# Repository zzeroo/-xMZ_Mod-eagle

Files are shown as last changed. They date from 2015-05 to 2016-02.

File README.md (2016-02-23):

# xMZ-Mod-Touch Eagle Files

Eagle files for the 'xMZ-Mod-Touch' project.

# Material Listen (BOM)

Die Material Listen werden aus den Eagle Zeichnungen gewonnen. Hierzu werden in
Eagle zunächst über den "design link" alle Bauteile in der Farnell Datenbank
gesucht.
Anschließend wird diese Liste gespeichert.

* Datei: "Deckelplatine $VERSION-order.txt"

Danach wird das bom.ulp in Eagle ausgeführt. Folgende Einstellungen sind zu
wählen:

	Listen-Typ: Werte (Häckchen unter "Attribute auflisten" setzen)
	Ausgabeformat: CSV

Diese Datei wird ebenfalls gespeichert.

* Datei: "Deckelplatine $VERSION BOM.csv"

### Farnell BOM Import

Farnell bietet die Möglichkeit über eine Web GUI die BOM Daten in eine
Bestellung umzuwandeln.

Format der CSV Datei für den Import:
- 3 Spalten
"Anzahl	Ordercode	Beschreibung"
- Dateiformat .xls

#Produktionsdaten
## Boardlayout Dateien

Einige der wichtigsten Ebenen (Drill, Solder, Paste) wurden einzeln mit der
Document (Layer 48) Ebene als PDF gedruckt

gs -dBATCH -dNOPAUSE -q -sDEVICE=pdfwrite -sOutputFile=Bodenplatine.pdf \
"Bodenplatine Dimensions.pdf" \
"Bodenplatine Placement TOP.pdf" \
"Bodenplatine PCB: TOP Layer.pdf" \
"Bodenplatine PCB: BOTTOM Layer.pdf" \
"Bodenplatine TOP Paste.pdf" \
"Bodenplatine TOP Solder Mask.pdf" \
"Bodenplatine Drill Drawing.pdf"

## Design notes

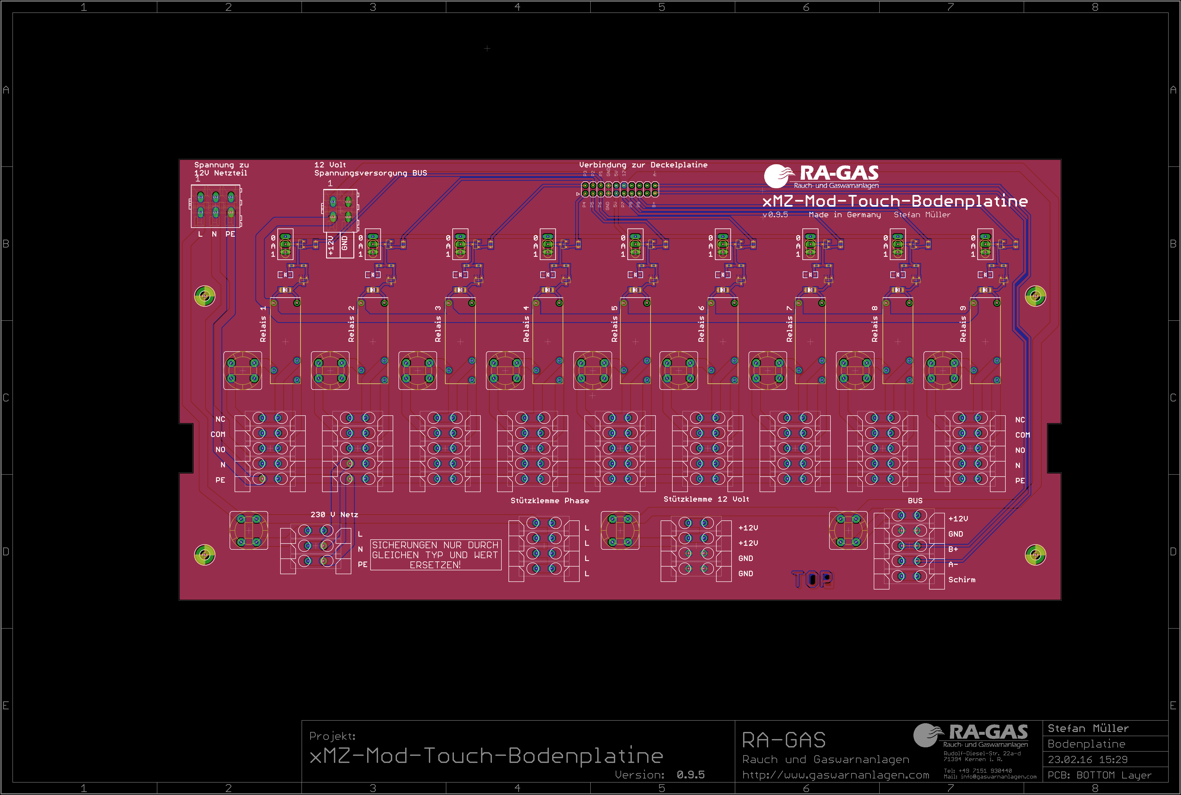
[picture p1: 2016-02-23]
Bodenplatine.png

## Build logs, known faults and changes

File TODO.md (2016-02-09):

# Deckelplatine

* Relais shift registers mit pull down/ pull up ausschalten bis der Banana Pro sie manuell aktiviert.

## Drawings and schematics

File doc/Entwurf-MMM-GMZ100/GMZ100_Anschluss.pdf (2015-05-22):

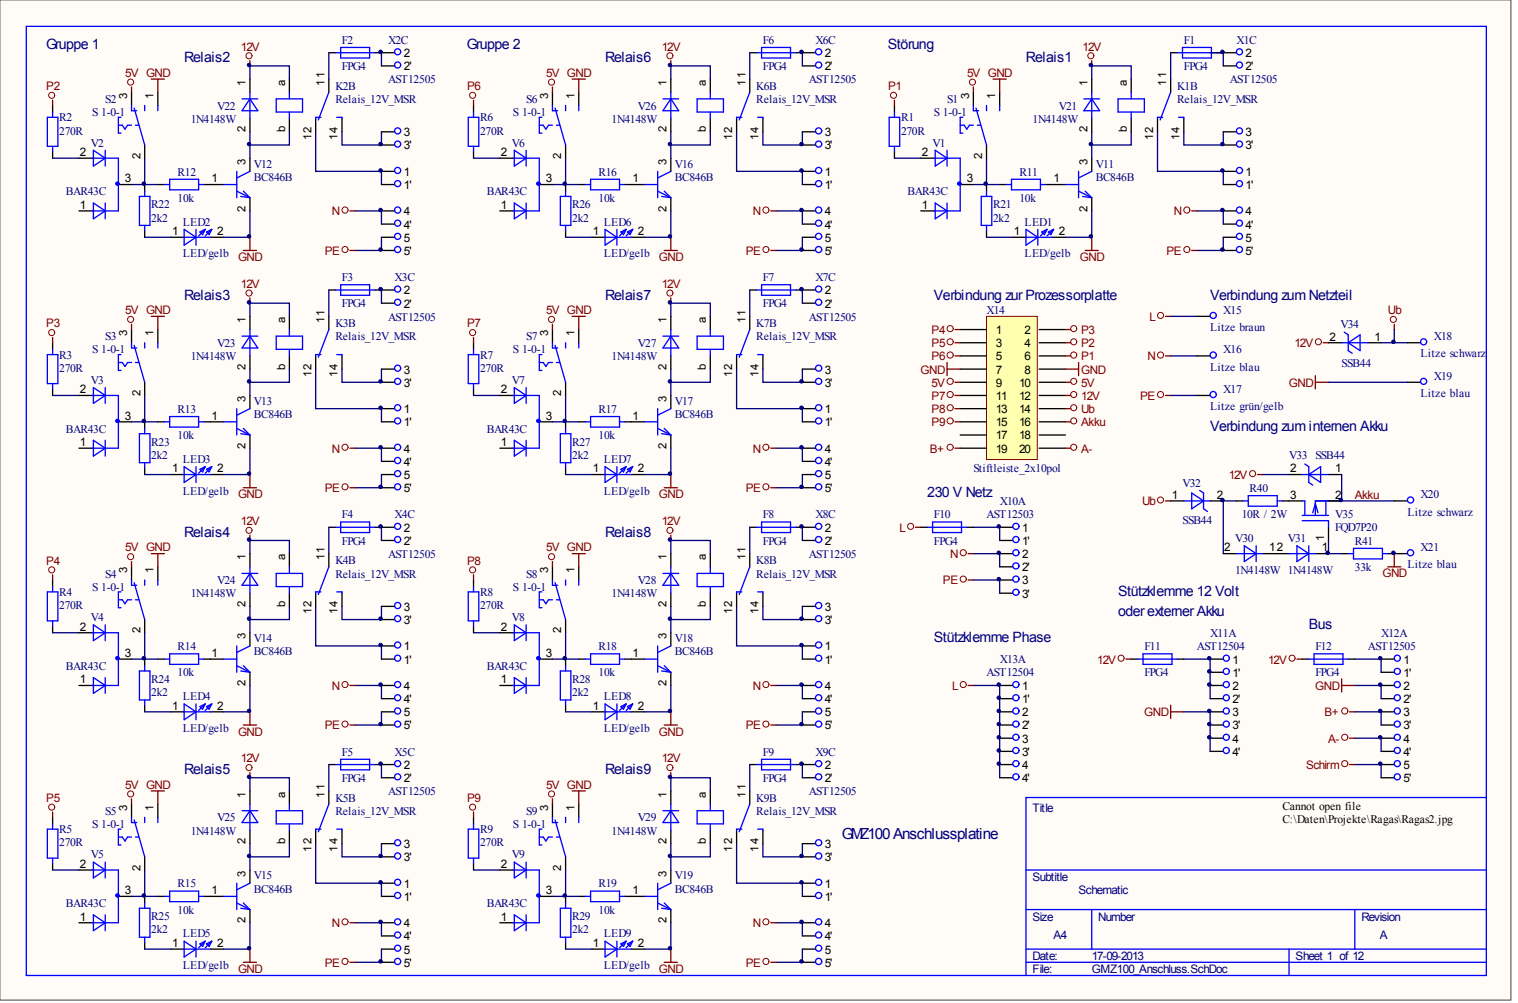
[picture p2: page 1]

Litze grün/gelb
Verbindung zum internen Akku

Cannot open file
C:\Daten\Projekte\Ragas\Ragas2.jpg

Size A4 | Number | Revision A

Date: 17-09-2013 | Sheet 1 of 12
File: GMZ100_Anschluss.SchDoc

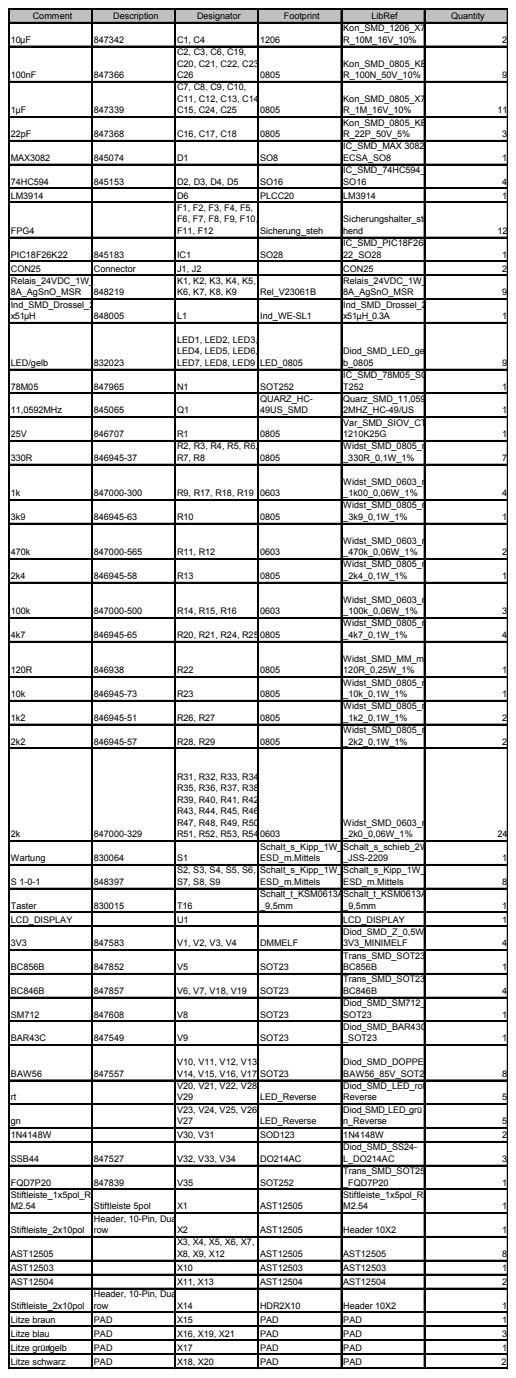
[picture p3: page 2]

Comment | Description | Designator | Footprint | LibRef | Quantity
10µF | 847342 | C1, C4 | 1206 | Kon_SMD_1206_X7 R_10M_16V_10% | 2

100nF | 847366 | C2, C3, C6, C19, C20, C21, C22, C23, C26 | 0805 | Kon_SMD_0805_KE R_100N_50V_10% | 9

1µF | 847339 | C7, C8, C9, C10, C11, C12, C13, C14, C15, C24, C25 | 0805 | Kon_SMD_0805_X7 R_1M_16V_10% | 11

22pF | 847368 | C16, C17, C18 | 0805 | Kon_SMD_0805_KE R_22P_50V_5% | 3

MAX3082 | 845074 | D1 | SO8 | IC_SMD_MAX 3082 ECSA_SO8 | 1

74HC594 | 845153 | D2, D3, D4, D5 | SO16 | IC_SMD_74HC594_ SO16 | 4

LM3914 | | D6 | PLCC20 | LM3914 | 1
FPG4 | | F1, F2, F3, F4, F5, F6, F7, F8, F9, F10, F11, F12 | Sicherung_steh | Sicherungshalter_ste hend | 12

PIC18F26K22 | 845183 | IC1 | SO28 | IC_SMD_PIC18F26k 22_SO28 | 1

CON25 | Connector | J1, J2 | | CON25 | 2
Relais_24VDC_1W_ 8A_AgSnO_MSR | 848219 | K1, K2, K3, K4, K5, K6, K7, K8, K9 | Rel_V23061B | Relais_24VDC_1W_ 8A_AgSnO_MSR | 9

Ind_SMD_Drossel_2 x51µH | 848005 | L1 | Ind_WE-SL1 | Ind_SMD_Drossel_2 x51µH_0.3A | 1

LED/gelb | 832023 | LED1, LED2, LED3, LED4, LED5, LED6, LED7, LED8, LED9 | LED_0805 | Diod_SMD_LED_gel b_0805 | 9

78M05 | 847965 | N1 | SOT252 | IC_SMD_78M05_SO T252 | 1

11,0592MHz | 845065 | Q1 | QUARZ_HC-49US_SMD | Quarz_SMD_11,059 2MHZ_HC-49/US | 1

25V | 846707 | R1 | 0805 | Var_SMD_SIOV_CT 1210K25G | 1

330R | 846945-37 | R2, R3, R4, R5, R6, R7, R8 | 0805 | Widst_SMD_0805_m _330R_0,1W_1% | 7

1k | 847000-300 | R9, R17, R18, R19 | 0603 | Widst_SMD_0603_m _1k00_0,06W_1% | 4

3k9 | 846945-63 | R10 | 0805 | Widst_SMD_0805_m _3k9_0,1W_1% | 1

470k | 847000-565 | R11, R12 | 0603 | Widst_SMD_0603_m _470k_0,06W_1% | 2

2k4 | 846945-58 | R13 | 0805 | Widst_SMD_0805_m _2k4_0,1W_1% | 1

100k | 847000-500 | R14, R15, R16 | 0603 | Widst_SMD_0603_m _100k_0,06W_1% | 3

4k7 | 846945-65 | R20, R21, R24, R25 0805 | | Widst_SMD_0805_m _4k7_0,1W_1% | 4

120R | 846938 | R22 | 0805 | Widst_SMD_MM_m 120R_0,25W_1% | 1

10k | 846945-73 | R23 | 0805 | Widst_SMD_0805_m _10k_0,1W_1% | 1

1k2 | 846945-51 | R26, R27 | 0805 | Widst_SMD_0805_m _1k2_0,1W_1% | 2

2k2 | 846945-57 | R28, R29 | 0805 | Widst_SMD_0805_m _2k2_0,1W_1% | 2

2k | 847000-329 | R31, R32, R33, R34, R35, R36, R37, R38, R39, R40, R41, R42, R43, R44, R45, R46, R47, R48, R49, R50, R51, R52, R53, R54 0603 | | Widst_SMD_0603_m _2k0_0,06W_1% | 24

Wartung | 830064 | S1 | Schalt_s_Kipp_1W_ ESD_m.Mittels | Schalt_s_schieb_2W _JSS-2209 | 1

S 1-0-1 | 848397 | S2, S3, S4, S5, S6, S7, S8, S9 | Schalt_s_Kipp_1W_ ESD_m.Mittels | Schalt_s_Kipp_1W_ ESD_m.Mittels | 8

Taster | 830015 | T16 | Schalt_t_KSM0613A _9,5mm | Schalt_t_KSM0613A _9,5mm | 1

LCD_DISPLAY | | U1 | | LCD_DISPLAY | 1
3V3 | 847583 | V1, V2, V3, V4 | DMMELF | Diod_SMD_Z_0,5W_ 3V3_MINIMELF | 4

BC856B | 847852 | V5 | SOT23 | Trans_SMD_SOT23_ BC856B | 1

BC846B | 847857 | V6, V7, V18, V19 | SOT23 | Trans_SMD_SOT23_ BC846B | 4

SM712 | 847608 | V8 | SOT23 | Diod_SMD_SM712_ SOT23 | 1

BAR43C | 847549 | V9 | SOT23 | Diod_SMD_BAR43C _SOT23 | 1

BAW56 | 847557 | V10, V11, V12, V13, V14, V15, V16, V17 | SOT23 | Diod_SMD_DOPPEL BAW56_85V_SOT23 | 8

rt | | V20, V21, V22, V28, V29 | LED_Reverse | Diod_SMD_LED_rot_ Reverse | 5

gn | | V23, V24, V25, V26, V27 | LED_Reverse | Diod_SMD_LED_grü n_Reverse | 5

1N4148W | | V30, V31 | SOD123 | 1N4148W | 2
SSB44 | 847527 | V32, V33, V34 | DO214AC | Diod_SMD_SS24-L_DO214AC | 3

FQD7P20 | 847839 | V35 | SOT252 | Trans_SMD_SOT252 _FQD7P20 | 1

Stiftleiste_1x5pol_R M2.54 | Stiftleiste 5pol | X1 | AST12505 | Stiftleiste_1x5pol_R M2.54 | 1

Stiftleiste_2x10pol | Header, 10-Pin, Dual row | X2 | AST12505 | Header 10X2 | 1

AST12505 | | X3, X4, X5, X6, X7, X8, X9, X12 | AST12505 | AST12505 | 8

AST12503 | | X10 | AST12503 | AST12503 | 1
AST12504 | | X11, X13 | AST12504 | AST12504 | 2
Stiftleiste_2x10pol | Header, 10-Pin, Dual row | X14 | HDR2X10 | Header 10X2 | 1

Litze braun | PAD | X15 | PAD | PAD | 1
Litze blau | PAD | X16, X19, X21 | PAD | PAD | 3
Litze grün/gelb | PAD | X17 | PAD | PAD | 1
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

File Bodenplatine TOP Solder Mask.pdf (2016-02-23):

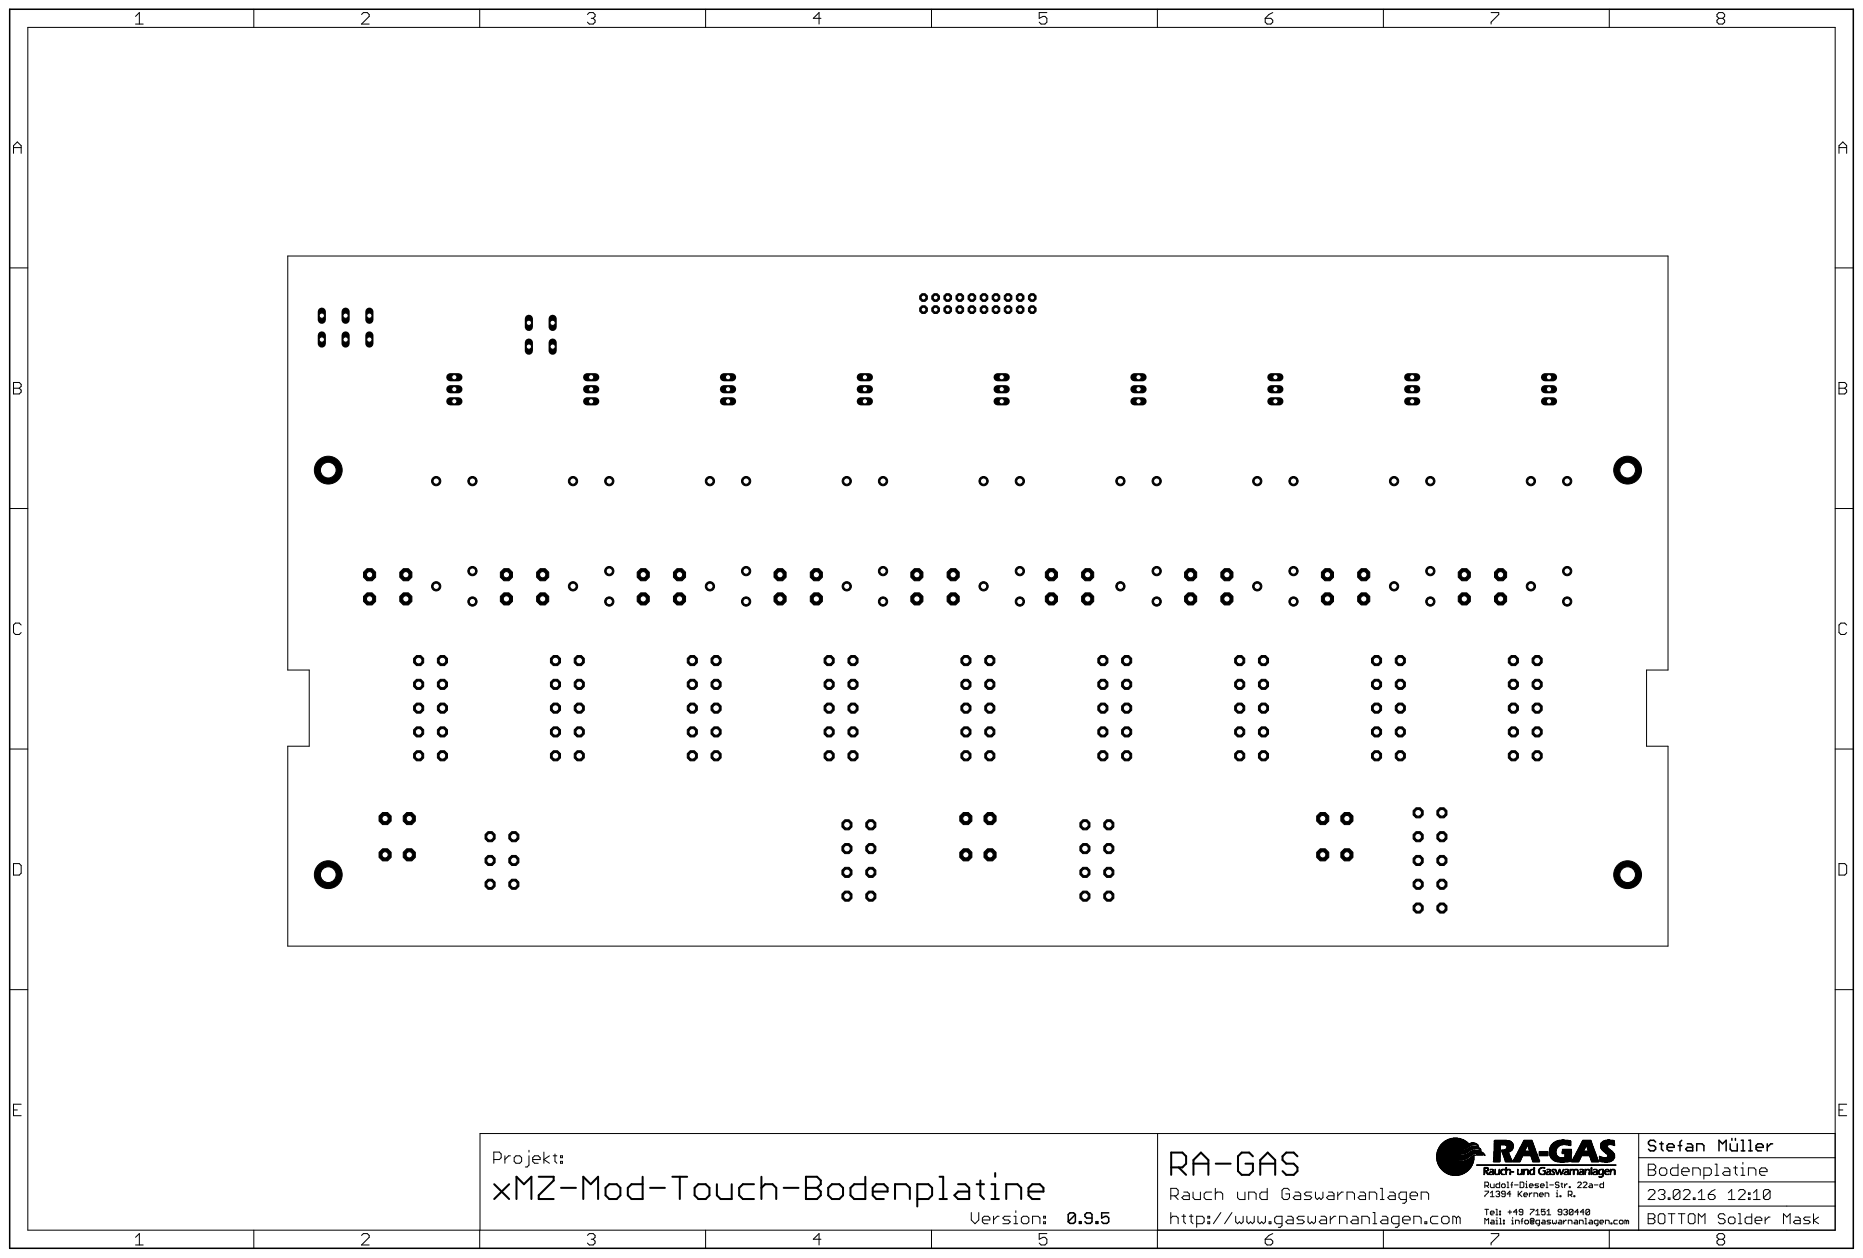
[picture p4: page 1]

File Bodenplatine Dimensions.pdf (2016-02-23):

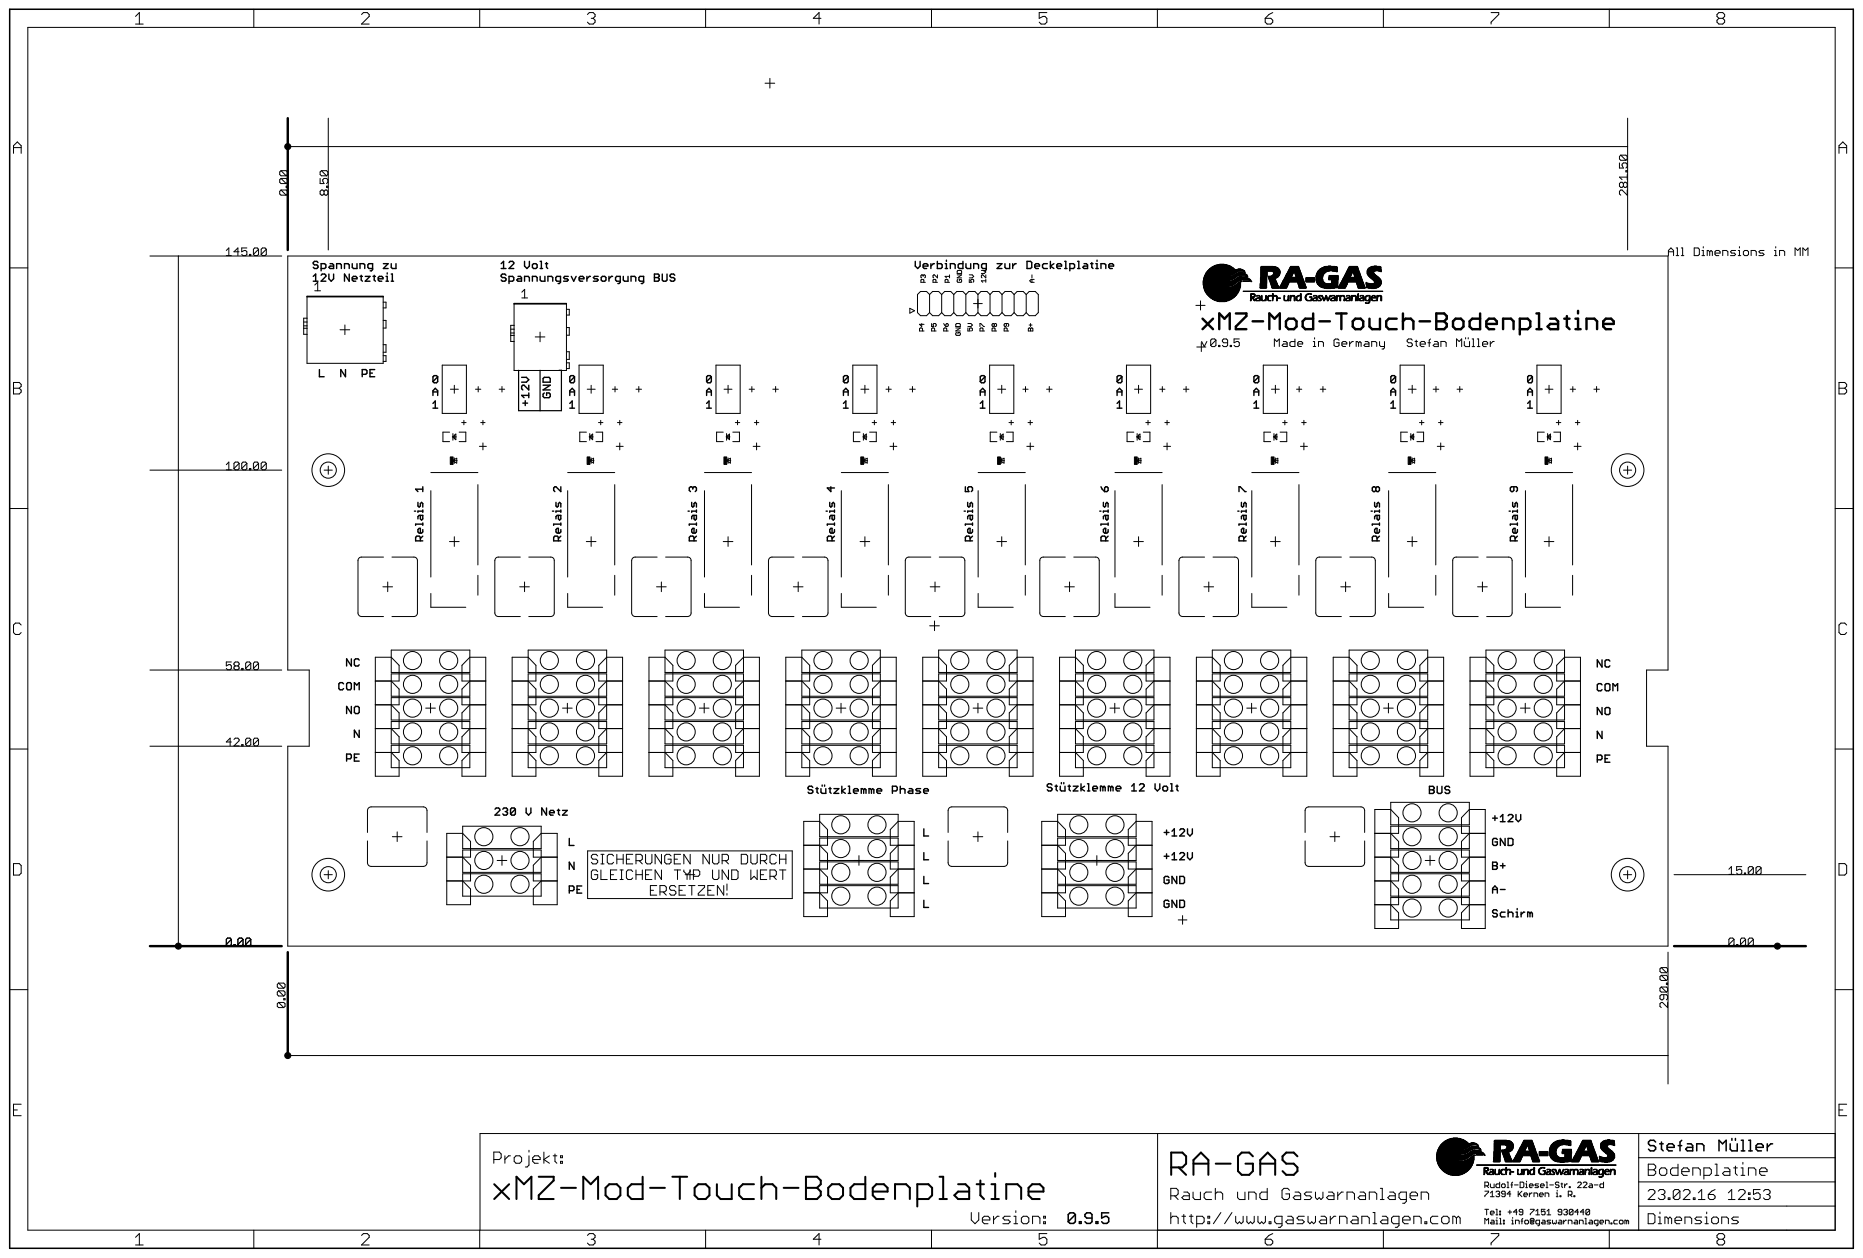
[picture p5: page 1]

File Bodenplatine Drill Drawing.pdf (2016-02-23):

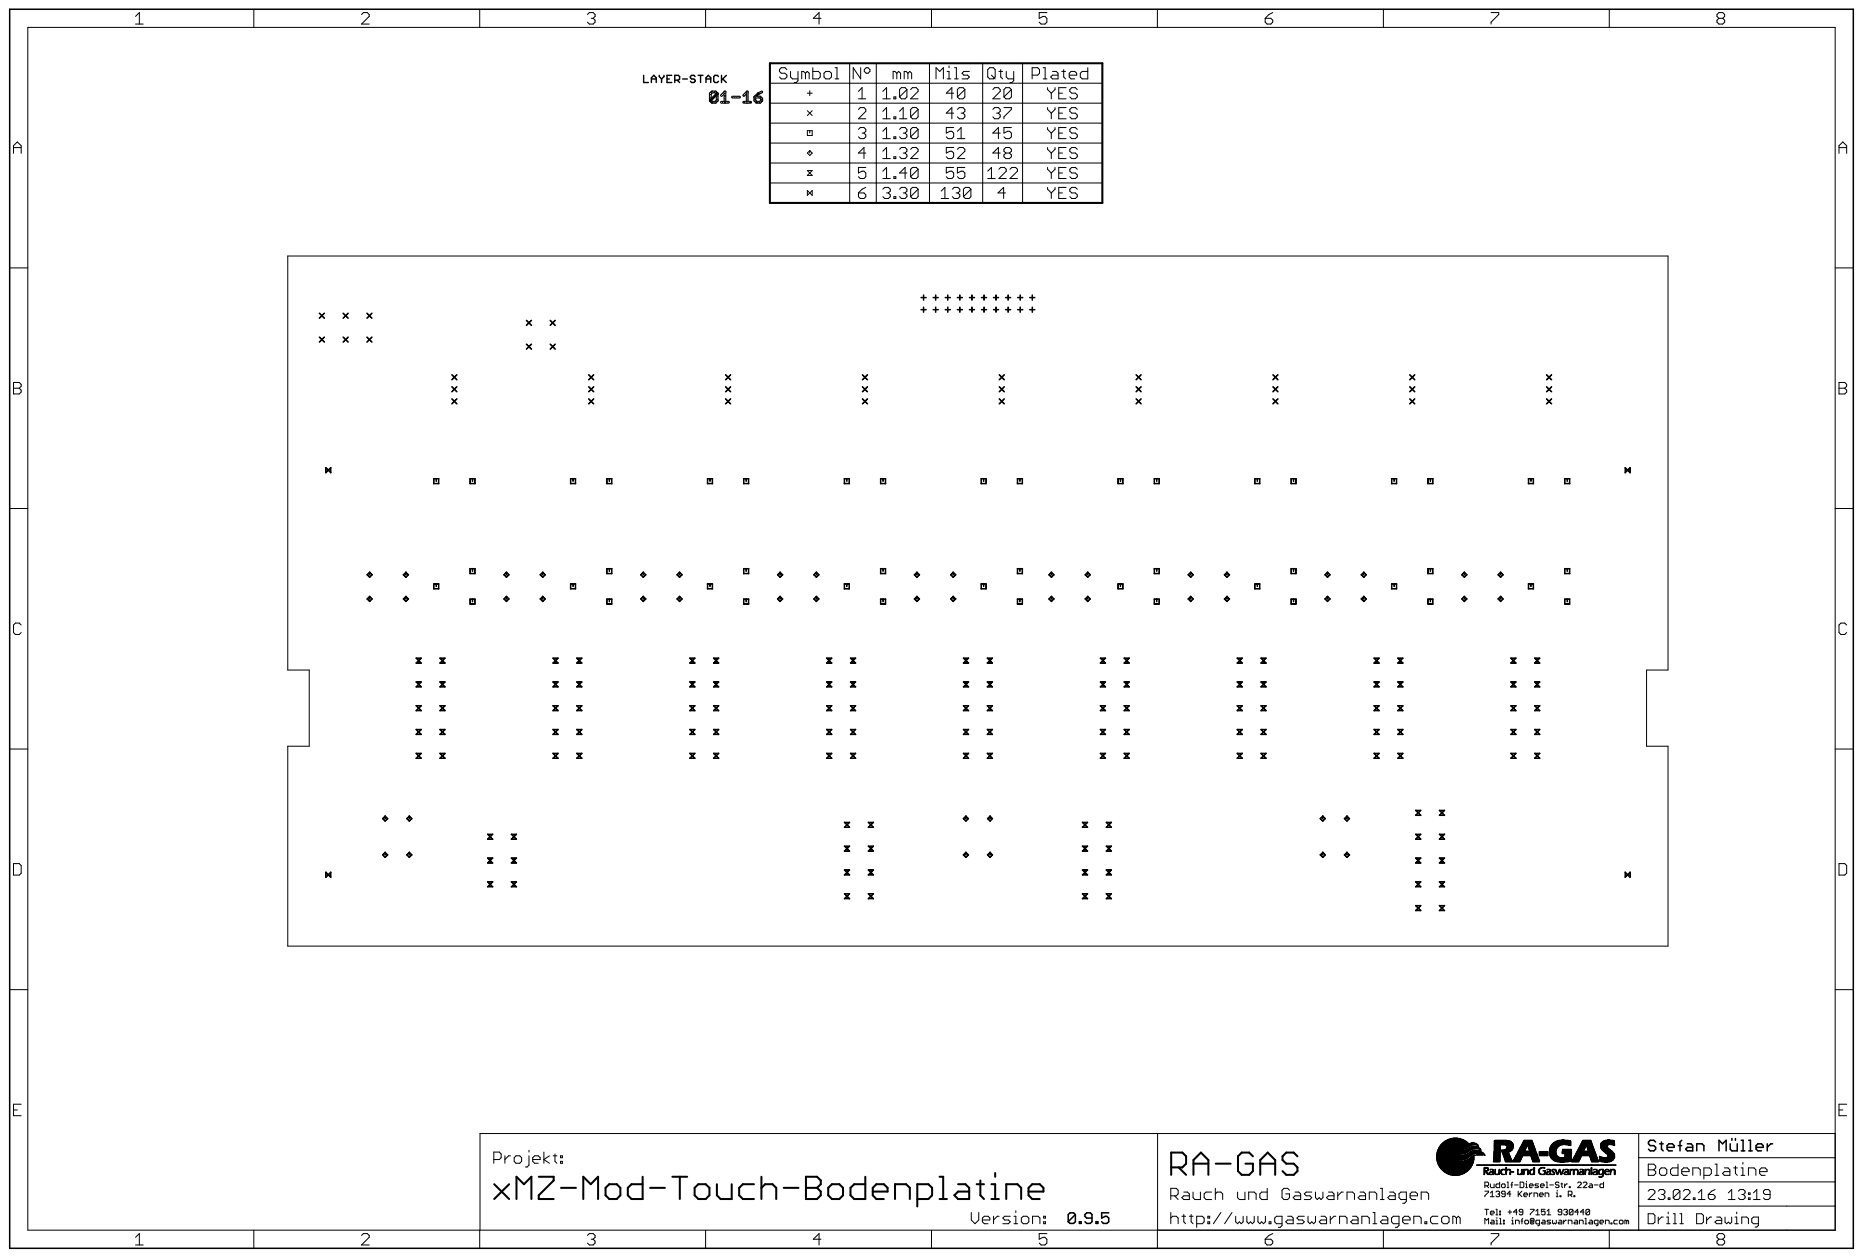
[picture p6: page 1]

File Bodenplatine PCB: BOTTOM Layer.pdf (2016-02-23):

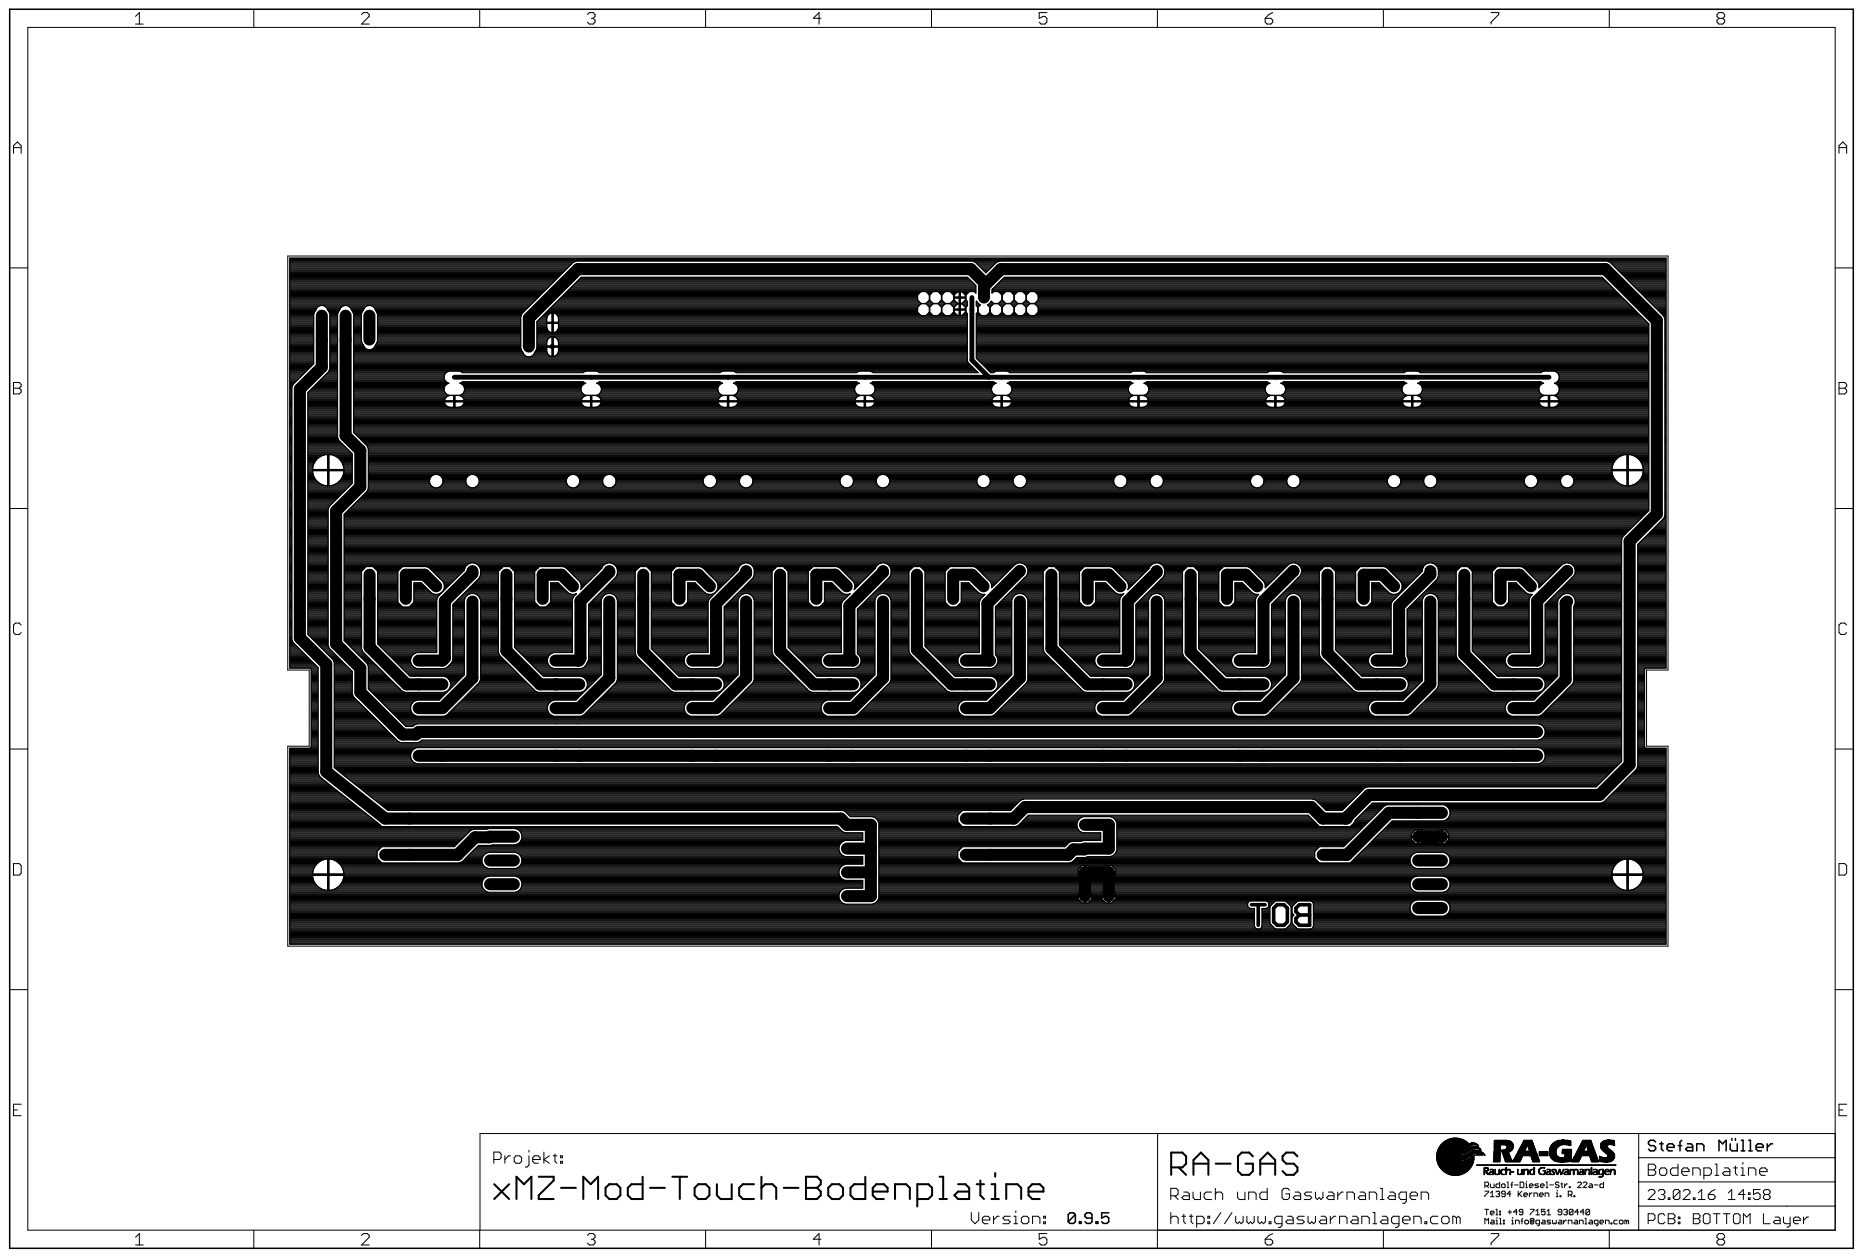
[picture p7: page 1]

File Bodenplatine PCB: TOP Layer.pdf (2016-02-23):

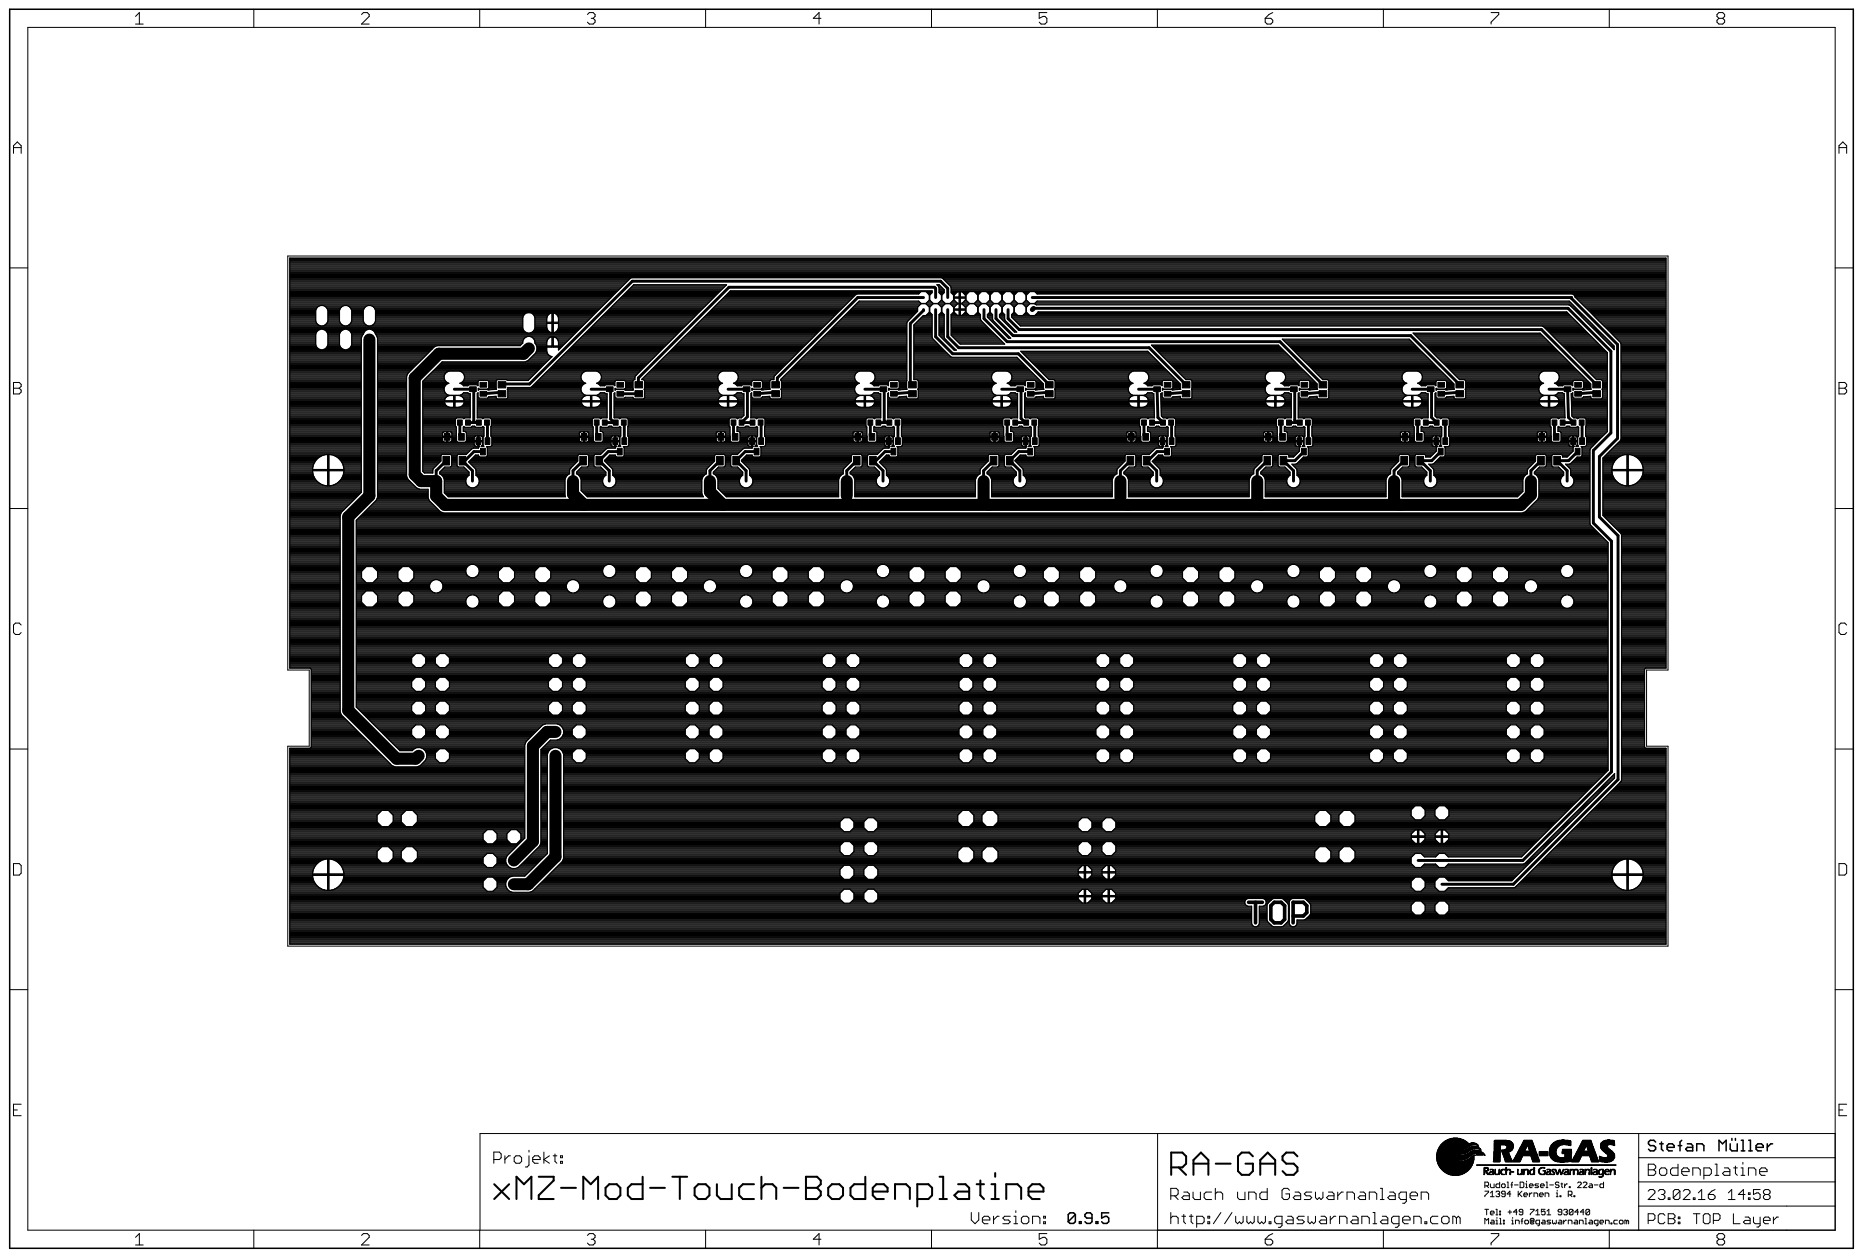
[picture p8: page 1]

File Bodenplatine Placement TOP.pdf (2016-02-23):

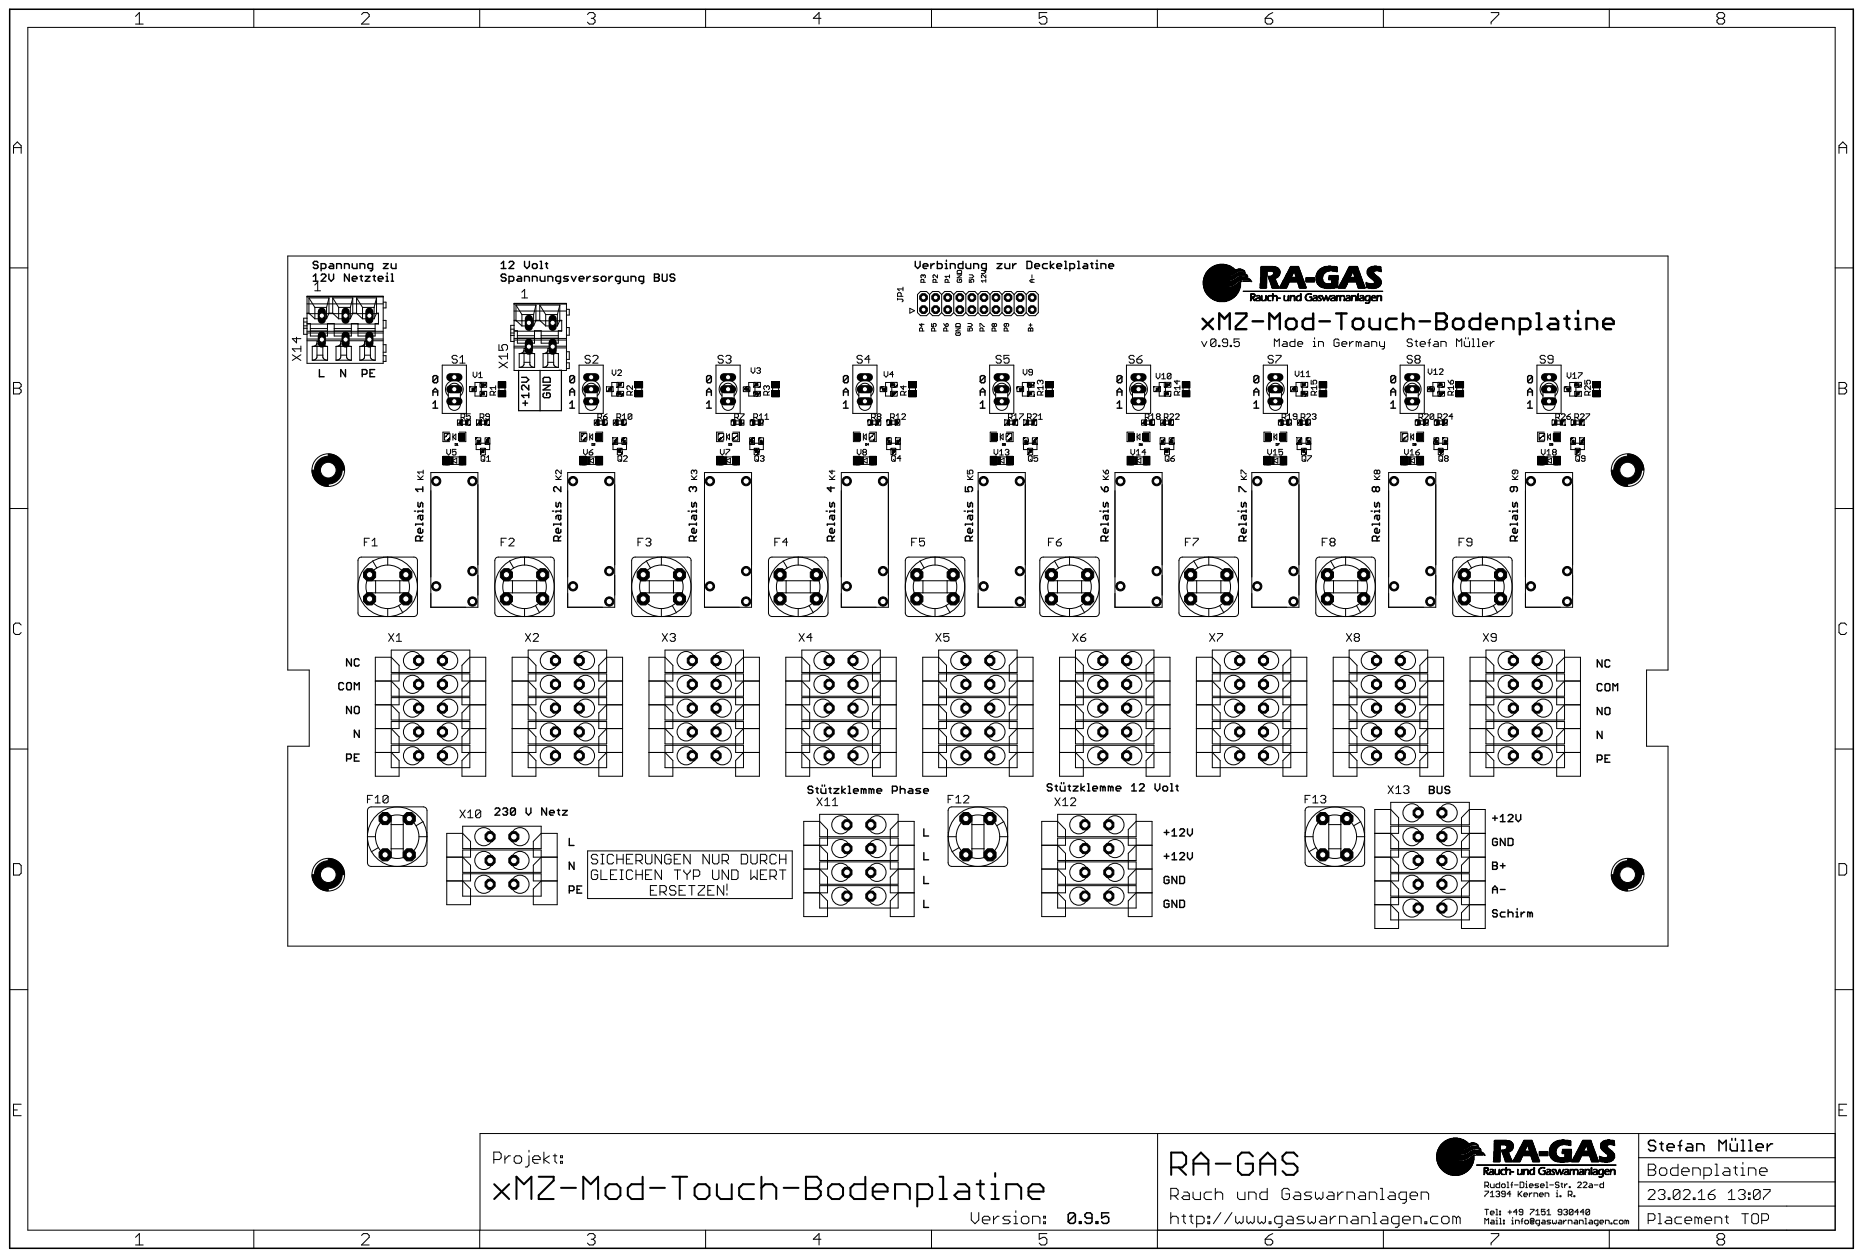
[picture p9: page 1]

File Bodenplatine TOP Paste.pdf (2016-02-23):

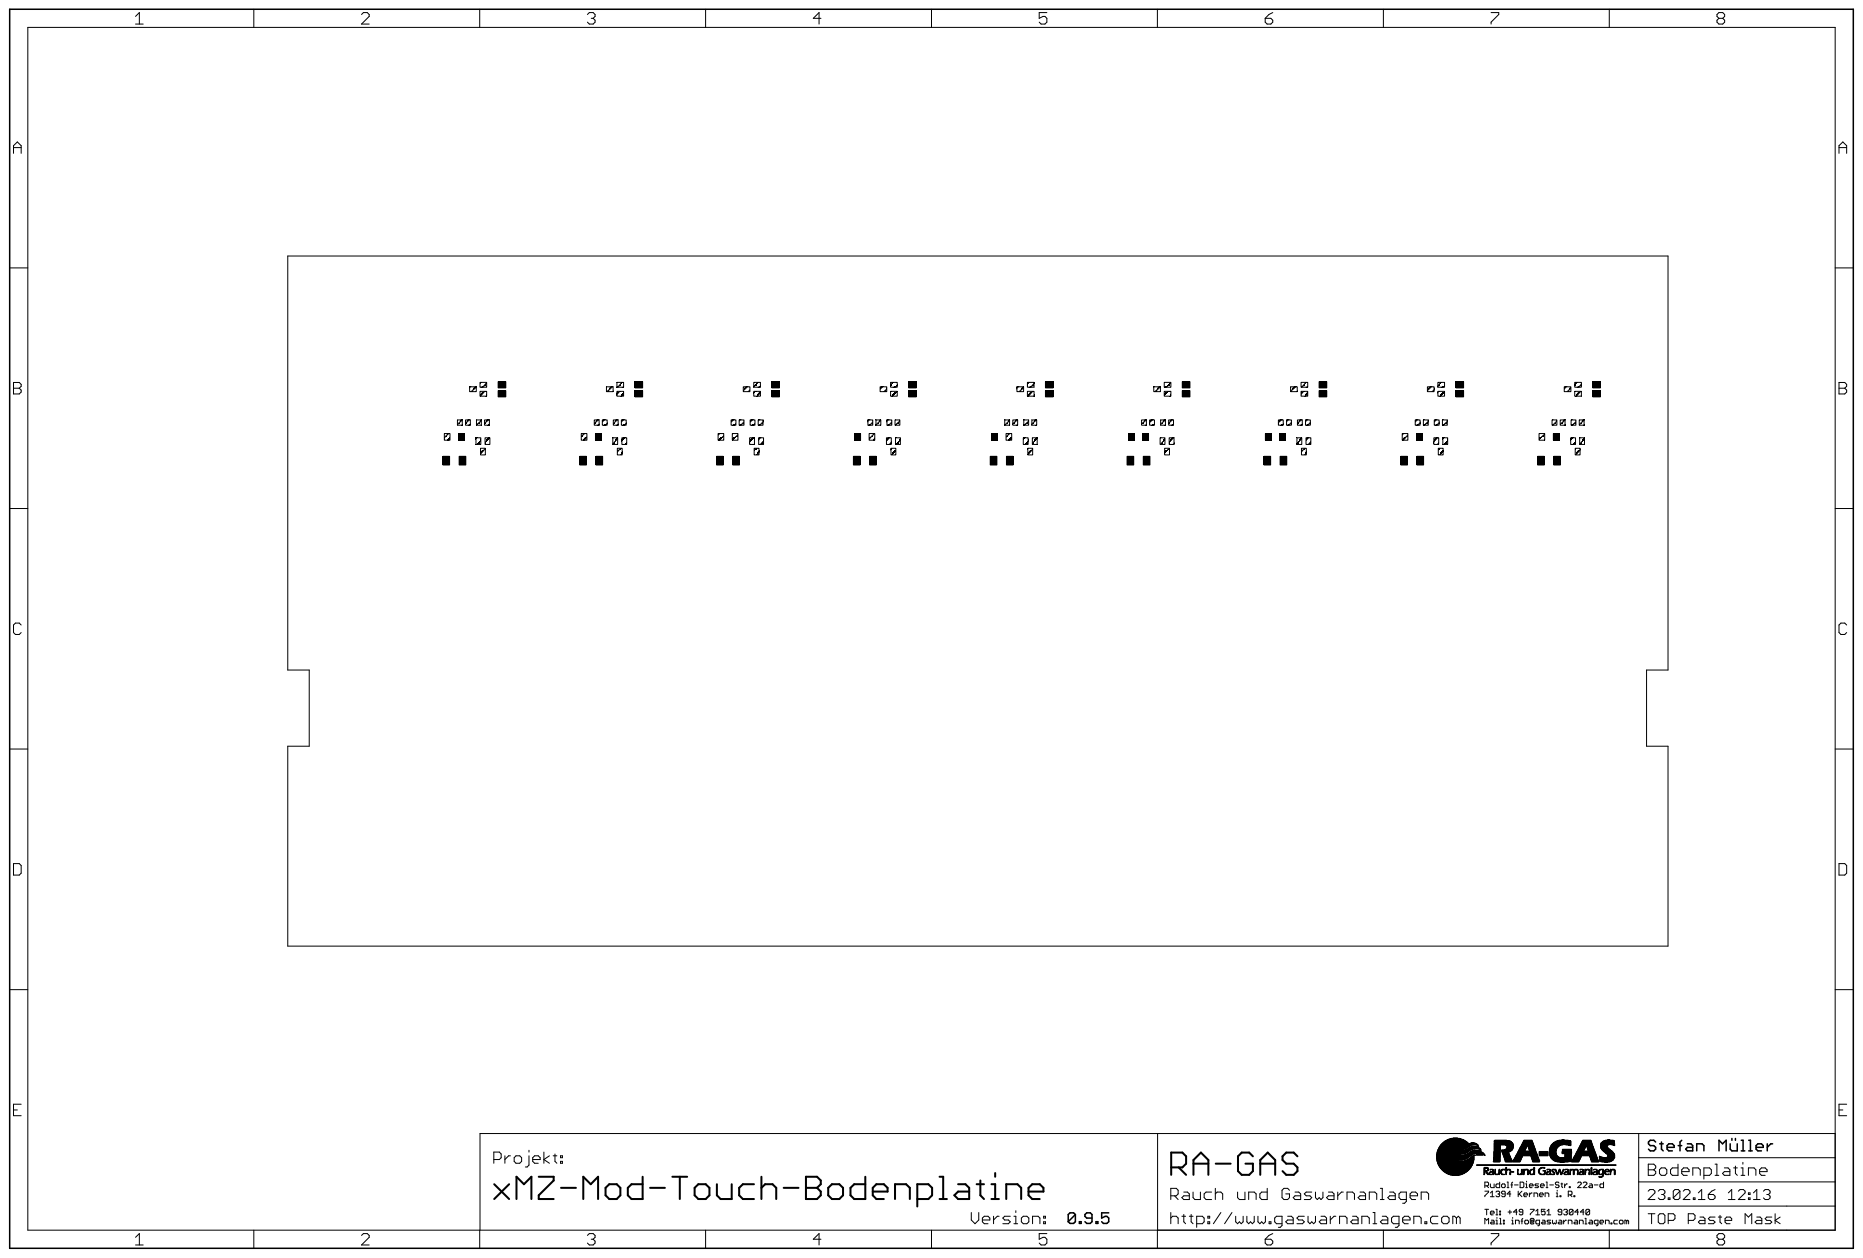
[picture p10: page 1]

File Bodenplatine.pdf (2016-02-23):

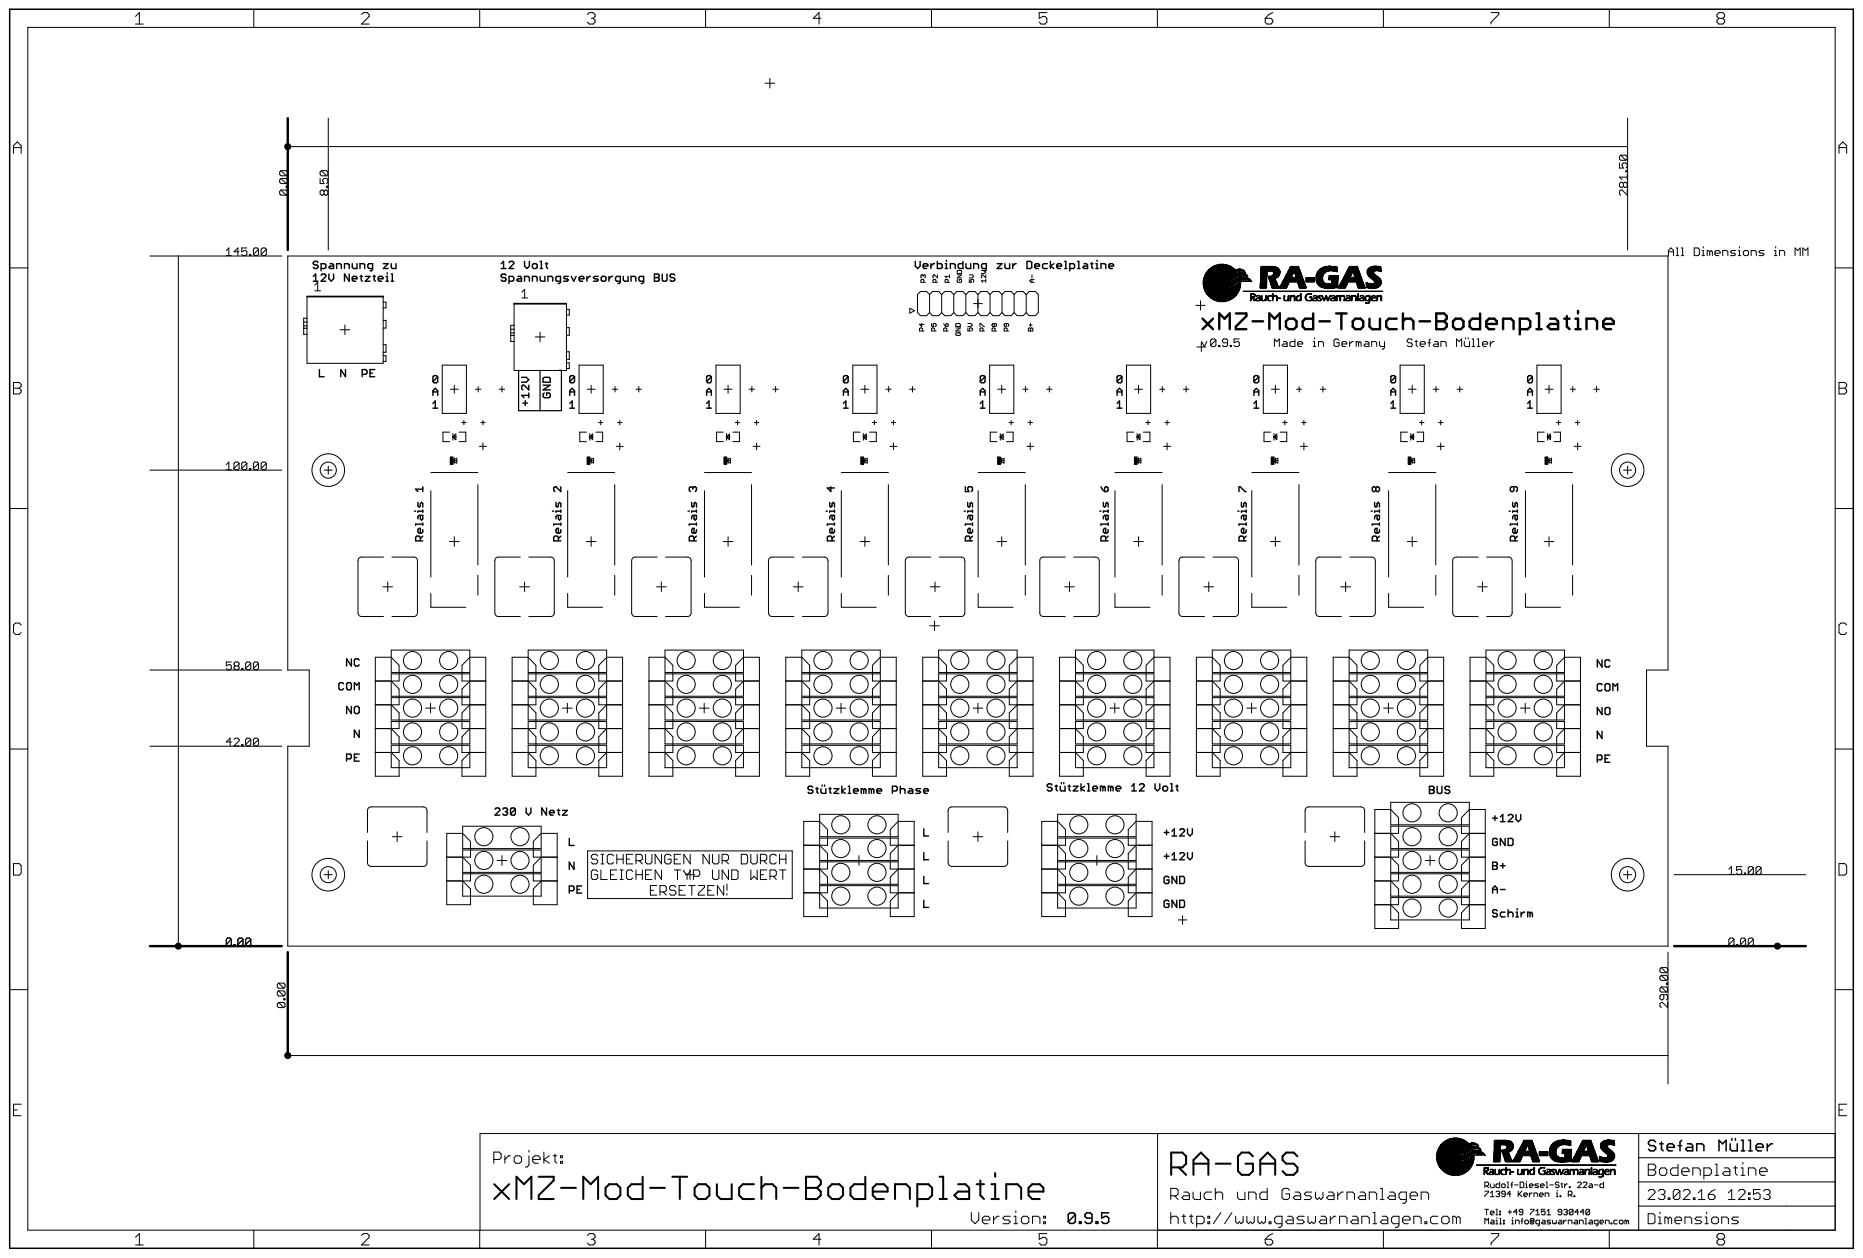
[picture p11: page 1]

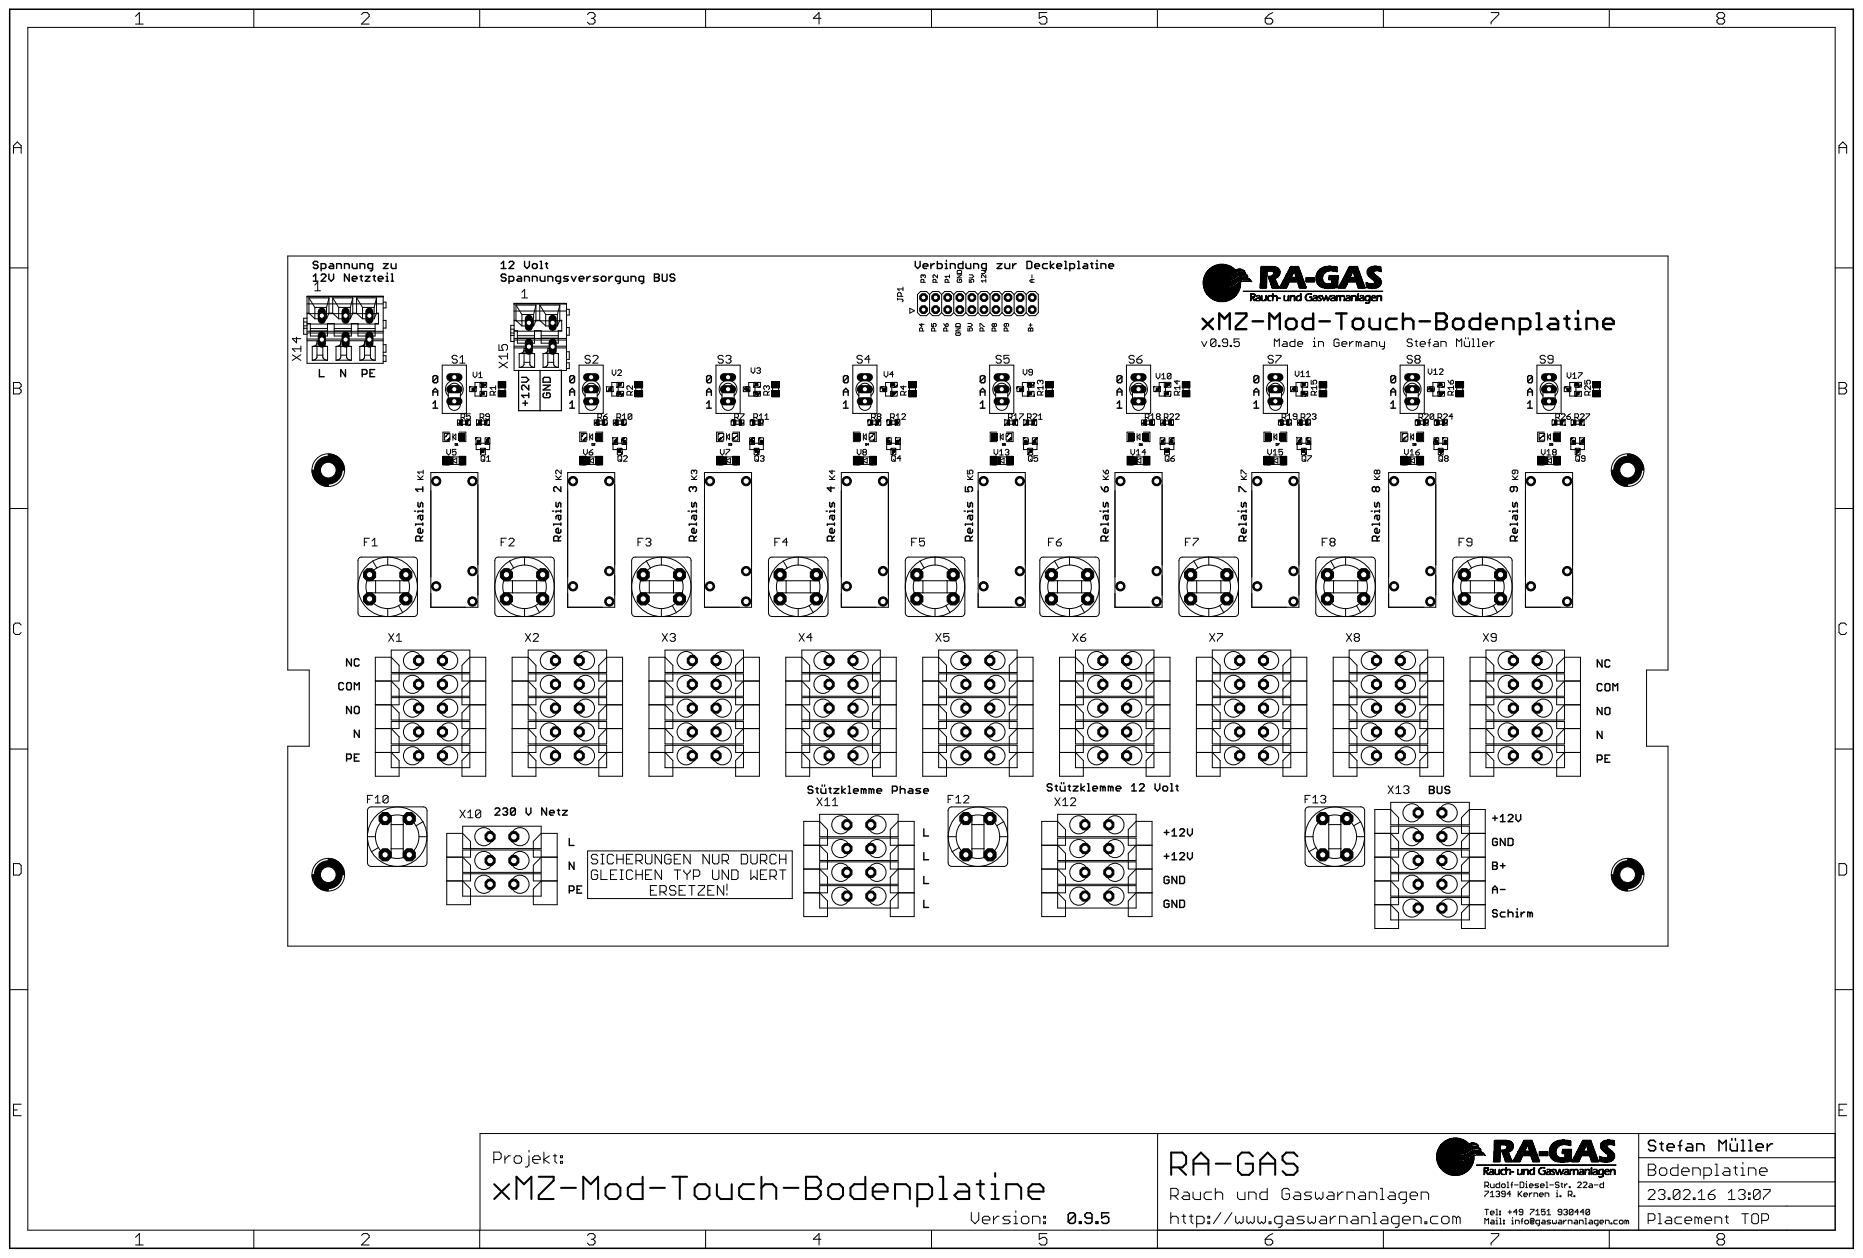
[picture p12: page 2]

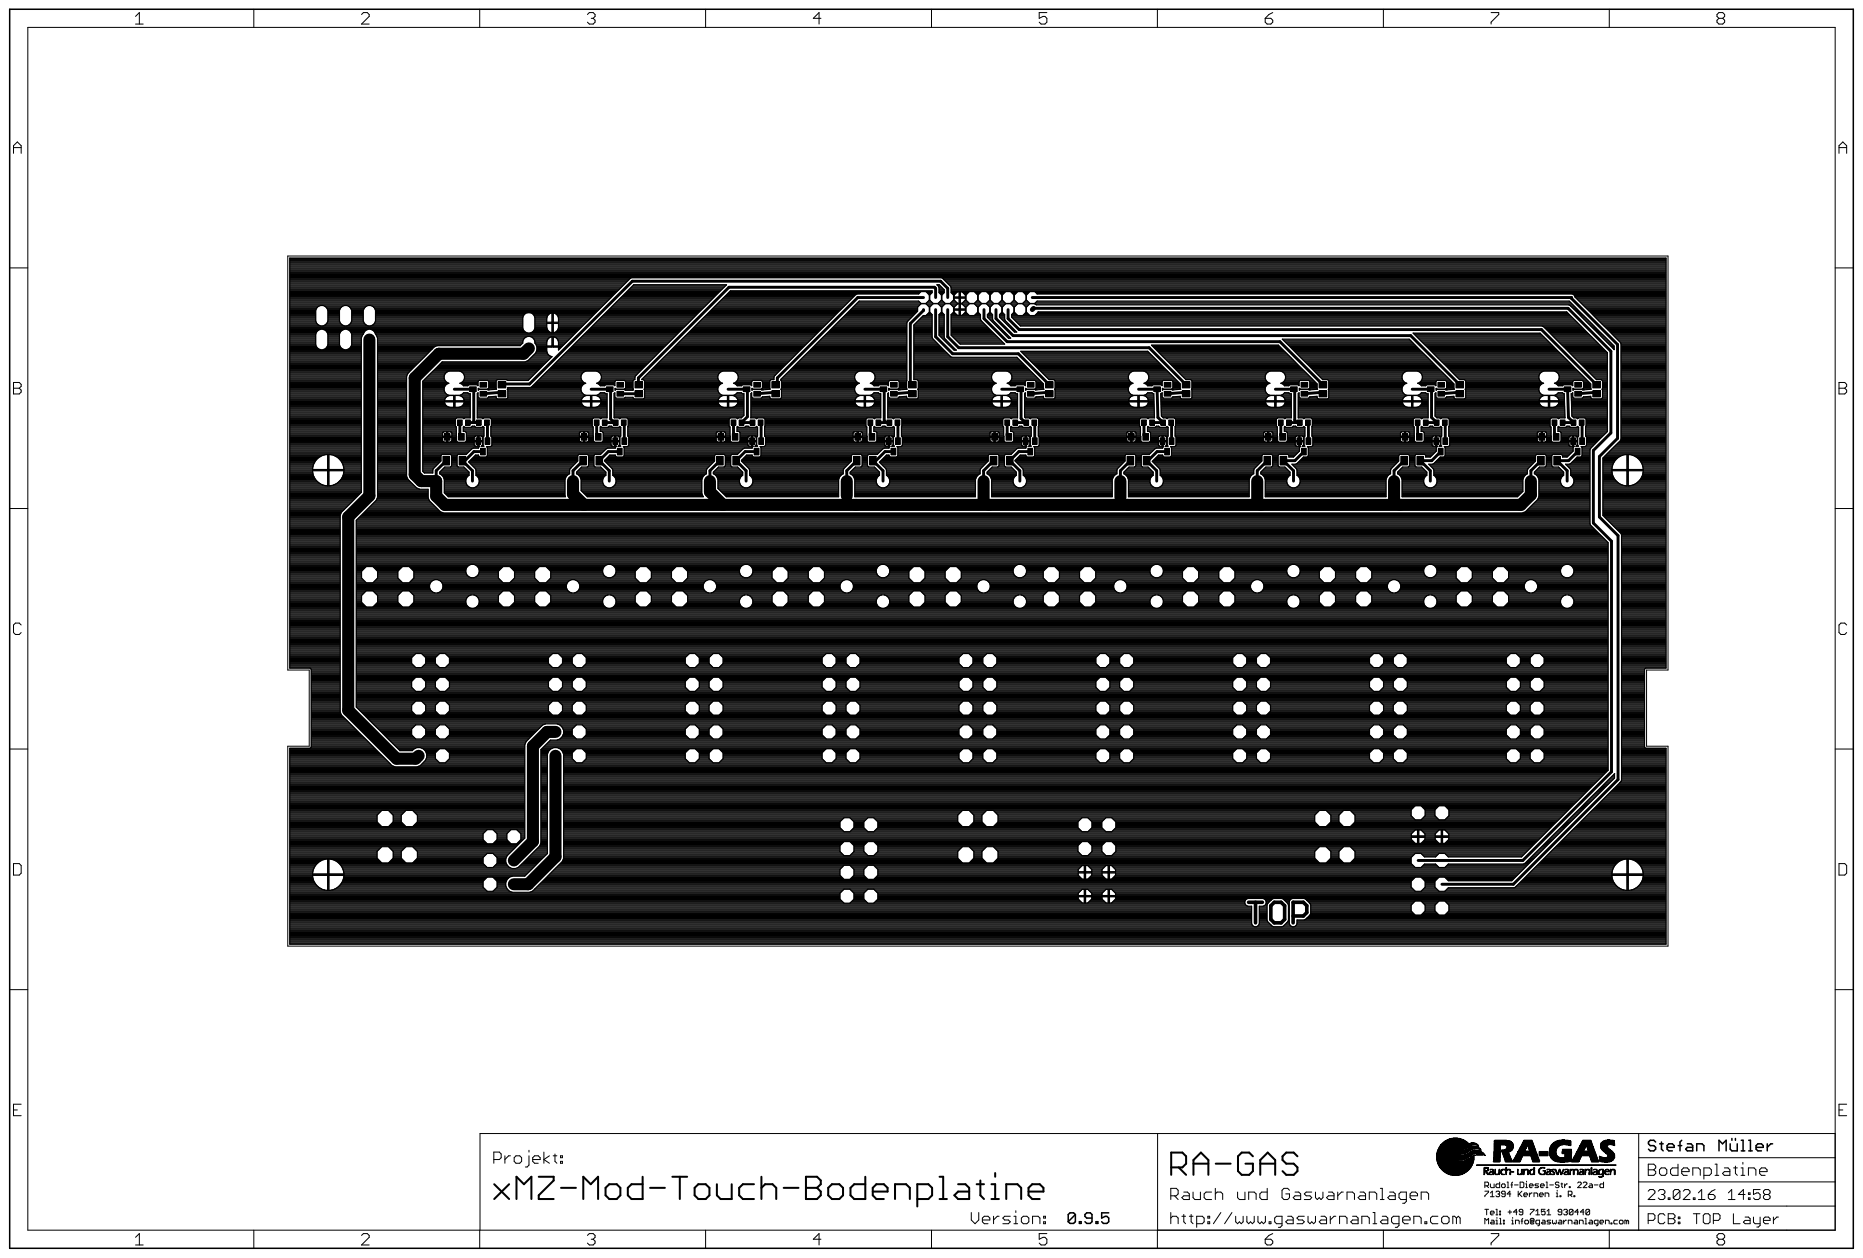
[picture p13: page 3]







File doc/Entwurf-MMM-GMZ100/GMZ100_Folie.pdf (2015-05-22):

# BCD 310 OT-FSC40,0


Außenkontur angepasst auf Bopla Gehäuse:

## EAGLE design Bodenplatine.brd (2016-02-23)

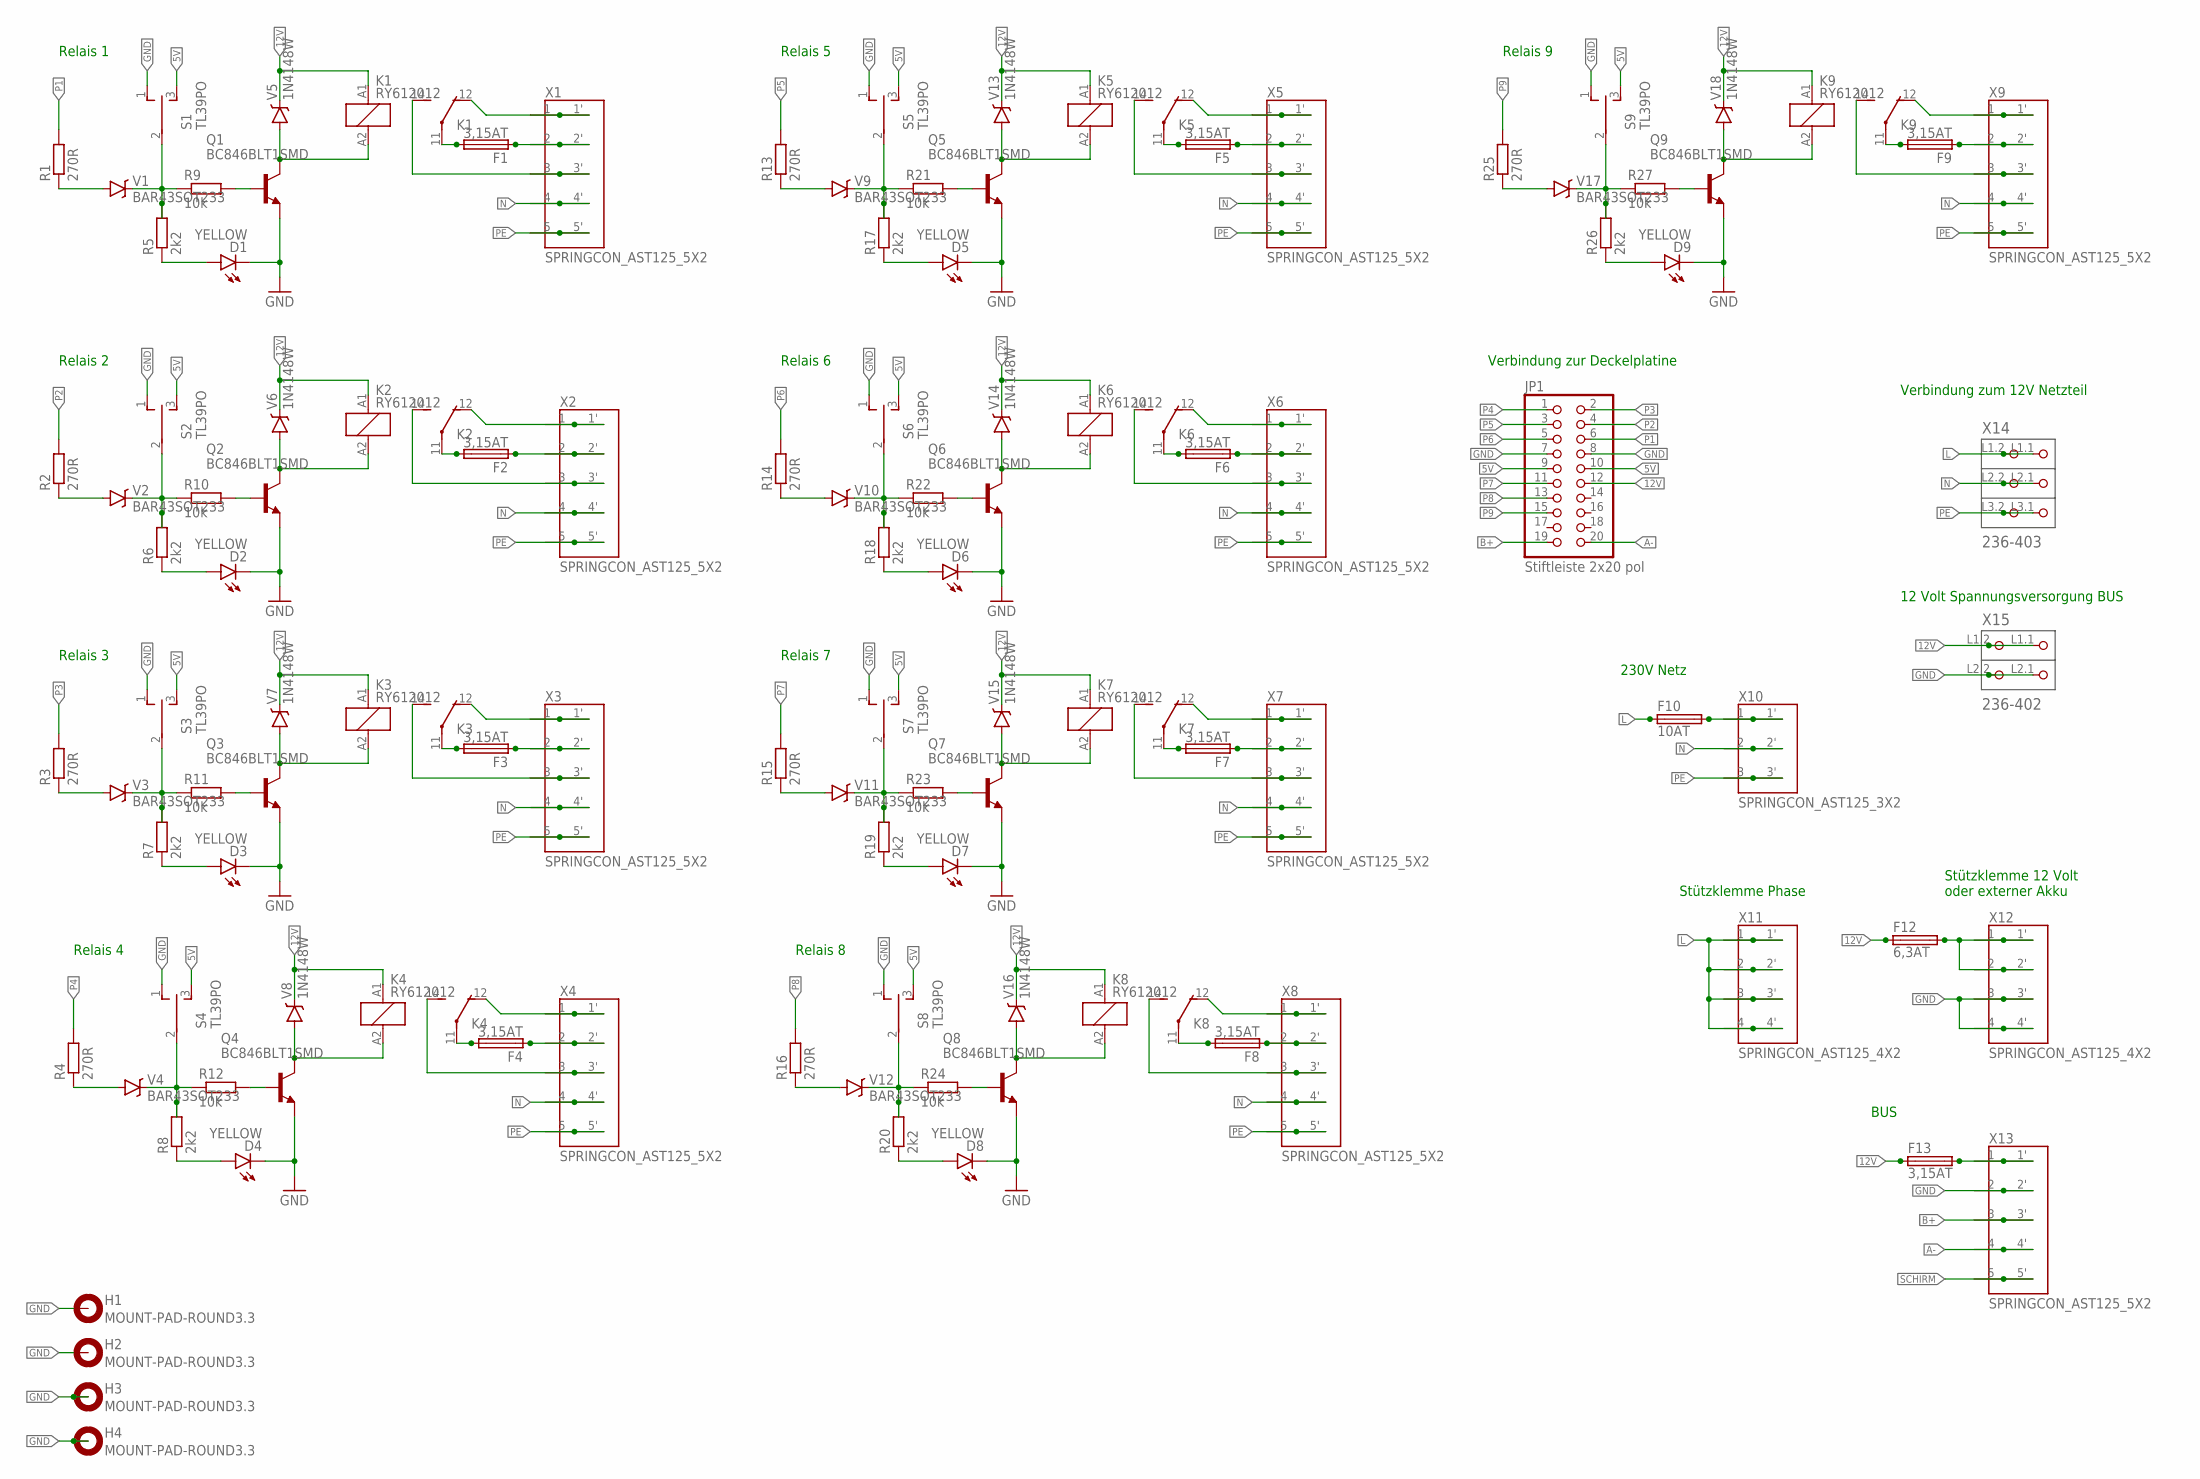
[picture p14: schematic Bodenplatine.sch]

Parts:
D1, D2, D3, D4, D5, D6, D7, D8, D9: YELLOW; LED-1206; MPN KP-3216SYC
F1, F2, F3, F4, F5, F6, F7, F8, F9, F13: 3,15AT; FPG4
F10: 10AT; FPG4
F12: 6,3AT; FPG4
H1, H2, H3, H4: MOUNT-PAD-ROUND3.3; 3,3-PAD
JP1: Stiftleiste 2x20 pol; 2X10; MPN 825440-5
K1, K2, K3, K4, K5, K6, K7, K8, K9: RY612012; RY-II; MPN V23061B1005A301
Q1, Q2, Q3, Q4, Q5, Q6, Q7, Q8, Q9: BC846BLT1SMD; SOT23; MPN BC846BWT1G
R1, R2, R3, R4, R13, R14, R15, R16, R25: 270R; M0805; MPN MC01W08055270R
R5, R6, R7, R8, R17, R18, R19, R20, R26: 2k2; R0603; MPN MC0063W060352K2
R9, R10, R11, R12, R21, R22, R23, R24, R27: 10k; R0603; MPN CPF0603B10KE1
S1, S2, S3, S4, S5, S6, S7, S8, S9: TL39PO; TL3XPO; MPN A103SYCQ04
V1, V2, V3, V4, V9, V10, V11, V12, V17: BAR43SOT233; SOT23; MPN BAR43
V5, V6, V7, V8, V13, V14, V15, V16, V18: 1N4148W; MINIMELF; MPN LL4148-GS08
X1, X2, X3, X4, X5, X6, X7, X8, X9, X13: SPRINGCON_AST125_5X2
X10: SPRINGCON_AST125_3X2
X11, X12: SPRINGCON_AST125_4X2
X14: 236-403; P-236-403; MPN 236-403
X15: 236-402; P-236-402; MPN 236-402

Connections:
5V: JP1.9, JP1.10, S1.3 (S), S2.3 (S), S3.3 (S), S4.3 (S), S5.3 (S), S6.3 (S), S7.3 (S), S8.3 (S), S9.3 (S)
12V: F12.1, F12.1' (1), F13.1, F13.1' (1), JP1.12, K1.A1 (1), K2.A1 (1), K3.A1 (1), K4.A1 (1), K5.A1 (1), K6.A1 (1), K7.A1 (1), K8.A1 (1), K9.A1 (1), V5.C, V6.C, V7.C, V8.C, V13.C, V14.C, V15.C, V16.C, V18.C, X15.L1.1 (P1.1), X15.L1.2 (P1.2)
A-: JP1.20, X13.4, X13.4' (4)
B+: JP1.19, X13.3, X13.3' (3)
GND: D1.C, D2.C, D3.C, D4.C, D5.C, D6.C, D7.C, D8.C, D9.C, H1.B3,3, H2.B3,3, H3.B3,3, H4.B3,3, JP1.7, JP1.8, Q1.2 (E), Q2.2 (E), Q3.2 (E), Q4.2 (E), Q5.2 (E), Q6.2 (E), Q7.2 (E), Q8.2 (E), Q9.2 (E), S1.1 (O), S2.1 (O), S3.1 (O), S4.1 (O), S5.1 (O), S6.1 (O), S7.1 (O), S8.1 (O), S9.1 (O), X12.3, X12.3' (3), X12.4, X12.4' (4), X13.2, X13.2' (2), X15.L2.1 (P2.1), X15.L2.2 (P2.2)
L: F10.1, F10.1' (1), X11.1, X11.1' (1), X11.2, X11.2' (2), X11.3, X11.3' (3), X11.4, X11.4' (4), X14.L1.1 (P1.1), X14.L1.2 (P1.2)
N: X1.4, X1.4' (4), X2.4, X2.4' (4), X3.4, X3.4' (4), X4.4, X4.4' (4), X5.4, X5.4' (4), X6.4, X6.4' (4), X7.4, X7.4' (4), X8.4, X8.4' (4), X9.4, X9.4' (4), X10.2, X10.2' (2), X14.L2.1 (P2.1), X14.L2.2 (P2.2)
unnamed: F2.1, F2.1' (1), X2.2, X2.2' (2)
unnamed: K2.14 (S), X2.3, X2.3' (3)
unnamed: F2.2, F2.2' (2), K2.11
unnamed: K2.12 (O), X2.1, X2.1' (1)
unnamed: K2.A2 (2), Q2.3 (C), V6.A
unnamed: K3.14 (S), X3.3, X3.3' (3)
unnamed: R2.1, V2.1 (A)
unnamed: R6.2, R10.1, S2.2, V2.3 (C)
unnamed: D2.A, R6.1
unnamed: Q2.1 (B), R10.2
unnamed: F3.2, F3.2' (2), K3.11
unnamed: R3.1, V3.1 (A)
unnamed: R7.2, R11.1, S3.2, V3.3 (C)
unnamed: D3.A, R7.1
unnamed: Q3.1 (B), R11.2
unnamed: K3.A2 (2), Q3.3 (C), V7.A
unnamed: F3.1, F3.1' (1), X3.2, X3.2' (2)
unnamed: K3.12 (O), X3.1, X3.1' (1)
unnamed: K4.14 (S), X4.3, X4.3' (3)
unnamed: F4.2, F4.2' (2), K4.11
unnamed: R4.1, V4.1 (A)
unnamed: R8.2, R12.1, S4.2, V4.3 (C)
unnamed: D4.A, R8.1
unnamed: Q4.1 (B), R12.2
unnamed: K4.A2 (2), Q4.3 (C), V8.A
unnamed: F4.1, F4.1' (1), X4.2, X4.2' (2)
unnamed: K4.12 (O), X4.1, X4.1' (1)
unnamed: K5.14 (S), X5.3, X5.3' (3)
unnamed: F5.2, F5.2' (2), K5.11
unnamed: R13.1, V9.1 (A)
unnamed: R17.2, R21.1, S5.2, V9.3 (C)
unnamed: D5.A, R17.1
unnamed: Q5.1 (B), R21.2
unnamed: K5.A2 (2), Q5.3 (C), V13.A
unnamed: F5.1, F5.1' (1), X5.2, X5.2' (2)
unnamed: K5.12 (O), X5.1, X5.1' (1)
unnamed: K6.14 (S), X6.3, X6.3' (3)
unnamed: F6.2, F6.2' (2), K6.11
unnamed: R14.1, V10.1 (A)
unnamed: R18.2, R22.1, S6.2, V10.3 (C)
unnamed: D6.A, R18.1
unnamed: Q6.1 (B), R22.2
unnamed: K6.A2 (2), Q6.3 (C), V14.A
unnamed: F6.1, F6.1' (1), X6.2, X6.2' (2)
unnamed: K6.12 (O), X6.1, X6.1' (1)
unnamed: K7.14 (S), X7.3, X7.3' (3)
unnamed: F7.2, F7.2' (2), K7.11
unnamed: R15.1, V11.1 (A)
unnamed: R19.2, R23.1, S7.2, V11.3 (C)
unnamed: D7.A, R19.1
unnamed: Q7.1 (B), R23.2
unnamed: K7.A2 (2), Q7.3 (C), V15.A
unnamed: F7.1, F7.1' (1), X7.2, X7.2' (2)
unnamed: K7.12 (O), X7.1, X7.1' (1)
unnamed: K8.14 (S), X8.3, X8.3' (3)
unnamed: F8.2, F8.2' (2), K8.11
unnamed: R16.1, V12.1 (A)
unnamed: R20.2, R24.1, S8.2, V12.3 (C)
unnamed: D8.A, R20.1
unnamed: Q8.1 (B), R24.2
unnamed: K8.A2 (2), Q8.3 (C), V16.A
unnamed: F8.1, F8.1' (1), X8.2, X8.2' (2)
unnamed: K8.12 (O), X8.1, X8.1' (1)
unnamed: K9.14 (S), X9.3, X9.3' (3)
unnamed: F9.2, F9.2' (2), K9.11
unnamed: R25.1, V17.1 (A)
unnamed: R26.2, R27.1, S9.2, V17.3 (C)
unnamed: D9.A, R26.1
unnamed: Q9.1 (B), R27.2
unnamed: K9.A2 (2), Q9.3 (C), V18.A
unnamed: F9.1, F9.1' (1), X9.2, X9.2' (2)
unnamed: K9.12 (O), X9.1, X9.1' (1)
unnamed: K1.14 (S), X1.3, X1.3' (3)
unnamed: F1.2, F1.2' (2), K1.11
unnamed: R1.1, V1.1 (A)
unnamed: R5.2, R9.1, S1.2, V1.3 (C)
unnamed: D1.A, R5.1
unnamed: Q1.1 (B), R9.2
unnamed: K1.A2 (2), Q1.3 (C), V5.A
unnamed: F1.1, F1.1' (1), X1.2, X1.2' (2)
unnamed: K1.12 (O), X1.1, X1.1' (1)
unnamed: F10.2, F10.2' (2), X10.1, X10.1' (1)
unnamed: F13.2, F13.2' (2), X13.1, X13.1' (1)
unnamed: F12.2, F12.2' (2), X12.1, X12.1' (1), X12.2, X12.2' (2)
P1: JP1.6, R1.2
P2: JP1.4, R2.2
P3: JP1.2, R3.2
P4: JP1.1, R4.2
P5: JP1.3, R13.2
P6: JP1.5, R14.2
P7: JP1.11, R15.2
P8: JP1.13, R16.2
P9: JP1.15, R25.2
PE: X1.5, X1.5' (5), X2.5, X2.5' (5), X3.5, X3.5' (5), X4.5, X4.5' (5), X5.5, X5.5' (5), X6.5, X6.5' (5), X7.5, X7.5' (5), X8.5, X8.5' (5), X9.5, X9.5' (5), X10.3, X10.3' (3), X14.L3.1 (P3.1), X14.L3.2 (P3.2)
SCHIRM: X13.5, X13.5' (5)

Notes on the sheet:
Relais 2
Relais 3
Relais 4
Relais 5
Relais 6
Relais 7
Relais 8
Relais 9
Relais 1
Verbindung zur Deckelplatine
230V Netz
Stützklemme Phase
Stützklemme 12 Volt oder externer Akku
BUS
Verbindung zum 12V Netzteil
12 Volt Spannungsversorgung BUS

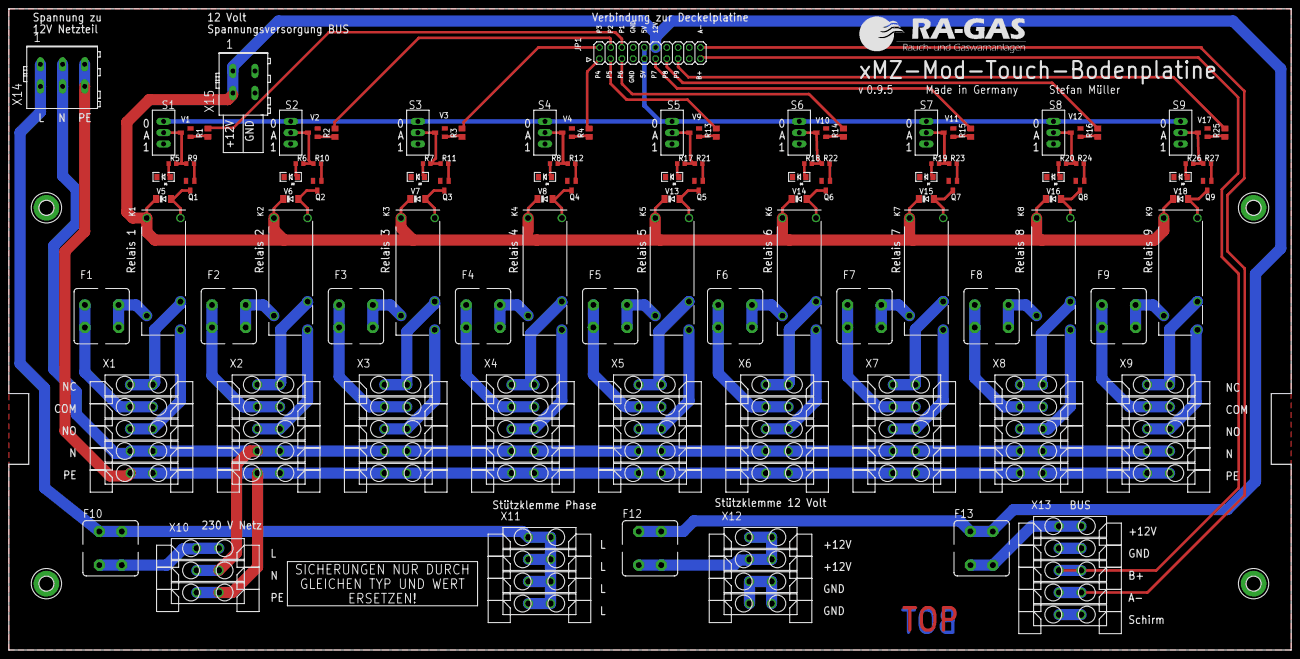
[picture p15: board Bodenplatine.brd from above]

Board: 2 copper layers, 290.0 x 145.0 mm, 118 parts (0 on the bottom side), 102 nets.

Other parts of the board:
DRILEGEND: DRILEGEND
U$1: TEXT_FUSE
U$2: TEXT_NAME_VERSION_AUTHOR
U$3: LOGO_RA-GAS
U$5: A3-LOC-RA-GAS

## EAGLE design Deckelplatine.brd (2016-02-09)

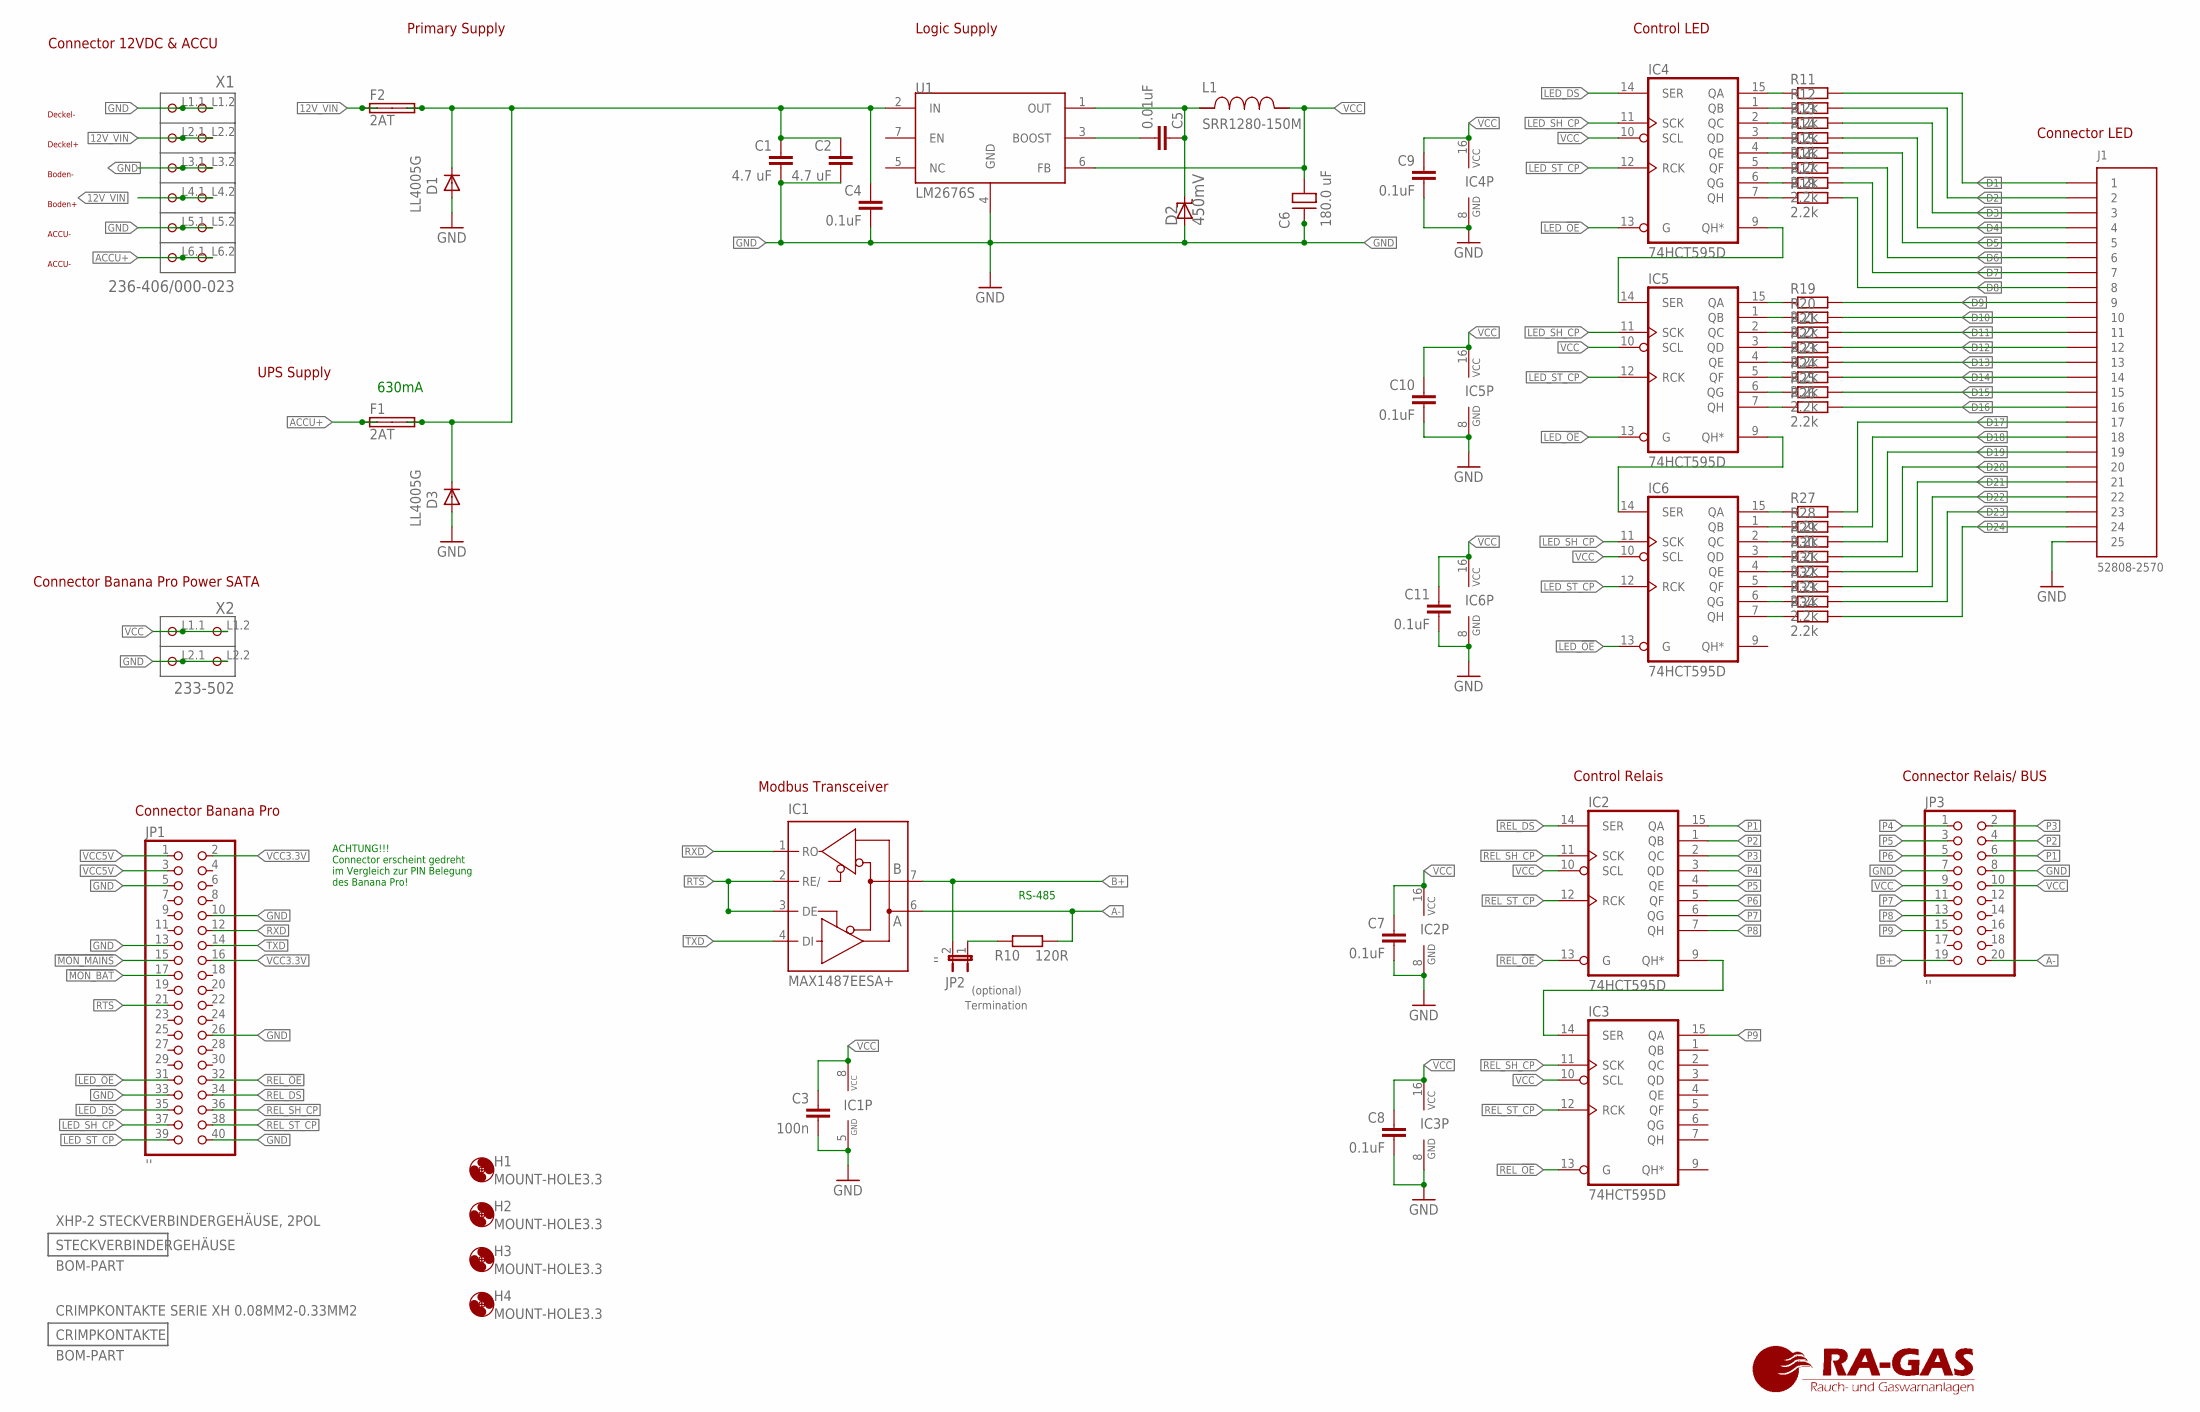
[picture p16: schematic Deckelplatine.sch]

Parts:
C1, C2: 4.7 uF; GRM21BR61E475MA12L; MPN GRM21BR61E475MA12L
C3: 100n; C0603; MPN C0603C104K8RACTU
C4: 0.1uF; 0805; MPN 08053C104KAT2A
C5: 0.01uF; GRM216R71H103KA01D; MPN GRM216R71H103KA01D
C6: 180.0 uF; SM_RADIAL_10MM; MPN 16SVP180MX
C7, C8, C9, C10, C11: 0.1uF; C0603; MPN C0603C104K8RACTU
D1, D3: LL4005G; MELF-MLL41; MPN LL4005G
D2: 450mV; SMB; MPN B340LB-13-F
F1, F2: 2AT; 01110005MR; MPN 01110005MR
H1, H2, H3, H4: MOUNT-HOLE3.3; 3,3
IC1: MAX1487EESA+; SO08; MPN MAX1487EESA+
IC2, IC3, IC4, IC5, IC6: 74HCT595D; SO16; MPN 74HCT595D
J1: 52808-2570; MPN 52808-2570
JP1: ''; 2X20; MPN M20-6112045
JP2: ''; JP1; MPN 825433-2
JP3: ''; 2X10; MPN 5103308-5
L1: SRR1280-150M; SRR1280; MPN MSS1278-153MLD
R10: 120R; R1206; MPN CRGH1206F120R
R11, R12, R13, R14, R15, R16, R17, R18, R19, R20, R21, R22, R23, R24, R25, R26, R27, R28, R29, R30, R31, R32, R33, R34: 2.2k; R0603; MPN RC0603FR-072K2L
U1: LM2676S; TO-263-7; MPN LM2676S-5.0/NOPB
X1: 236-406/000-023; P-236-406; MPN 236-406
X2: 233-502; P-233-502; MPN 233-502.

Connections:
12V_VIN: F2.1A, F2.1B, X1.L2.1 (P2.1), X1.L2.2 (P2.2), X1.L4.1 (P4.1), X1.L4.2 (P4.2)
!MON_BAT: JP1.17
!MON_MAINS: JP1.15
A-: IC1.6 (A), JP3.20, R10.2
ACCU+: F1.1A, F1.1B, X1.L6.1 (P6.1), X1.L6.2 (P6.2)
B+: IC1.7 (B), JP2.2, JP3.19
D1: J1.1, R11.2
D2: J1.2, R12.2
D3: J1.3, R13.2
D4: J1.4, R14.2
D5: J1.5, R15.2
D6: J1.6, R16.2
D7: J1.7, R17.2
D8: J1.8, R18.2
D9: J1.9, R19.2
D10: J1.10, R20.2
D11: J1.11, R21.2
D12: J1.12, R22.2
D13: J1.13, R23.2
D14: J1.14, R24.2
D15: J1.15, R25.2
D16: J1.16, R26.2
D17: J1.17, R27.2
D18: J1.18, R28.2
D19: J1.19, R29.2
D20: J1.20, R30.2
D21: J1.21, R31.2
D22: J1.22, R32.2
D23: J1.23, R33.2
D24: J1.24, R34.2
GND: C1.2, C2.2, C3.2, C4.2, C6.2 (-), C7.2, C8.2, C9.2, C10.2, C11.2, D1.A, D2.A, D3.A, IC1.5 (GND), IC2.8 (GND), IC3.8 (GND), IC4.8 (GND), IC5.8 (GND), IC6.8 (GND), J1.25, JP1.5, JP1.10, JP1.13, JP1.26, JP1.33, JP1.40, JP3.7, JP3.8, U1.4 (GND), X1.L1.1 (P1.1), X1.L1.2 (P1.2), X1.L3.1 (P3.1), X1.L3.2 (P3.2), X1.L5.1 (P5.1), X1.L5.2 (P5.2), X2.L2.1 (P2.1), X2.L2.2 (P2.2)
LED_!OE: IC4.13 (G), IC5.13 (G), IC6.13 (G), JP1.31
LED_DS: IC4.14 (SER), JP1.35
LED_SH_CP: IC4.11 (SCK), IC5.11 (SCK), IC6.11 (SCK), JP1.37
LED_ST_CP: IC4.12 (RCK), IC5.12 (RCK), IC6.12 (RCK), JP1.39
unnamed: IC5.9 (QH*), IC6.14 (SER)
unnamed: IC2.9 (QH*), IC3.14 (SER)
unnamed: C1.1, C2.1, C4.1, D1.C, D3.C, F1.2A, F1.2B, F2.2A, F2.2B, U1.2 (IN)
unnamed: IC4.9 (QH*), IC5.14 (SER)
unnamed: IC4.15 (QA), R11.1
unnamed: IC4.1 (QB), R12.1
unnamed: IC4.2 (QC), R13.1
unnamed: IC4.3 (QD), R14.1
unnamed: IC4.4 (QE), R15.1
unnamed: IC4.5 (QF), R16.1
unnamed: IC4.6 (QG), R17.1
unnamed: IC4.7 (QH), R18.1
unnamed: IC5.15 (QA), R19.1
unnamed: IC5.1 (QB), R20.1
unnamed: IC5.2 (QC), R21.1
unnamed: IC5.3 (QD), R22.1
unnamed: JP2.1, R10.1
unnamed: IC5.4 (QE), R23.1
unnamed: IC5.5 (QF), R24.1
unnamed: IC5.6 (QG), R25.1
unnamed: IC5.7 (QH), R26.1
unnamed: IC6.15 (QA), R27.1
unnamed: IC6.1 (QB), R28.1
unnamed: IC6.2 (QC), R29.1
unnamed: IC6.3 (QD), R30.1
unnamed: IC6.4 (QE), R31.1
unnamed: IC6.5 (QF), R32.1
unnamed: IC6.6 (QG), R33.1
unnamed: IC6.7 (QH), R34.1
unnamed: C5.2, U1.3 (BOOST)
unnamed: C5.1, D2.C, L1.1, U1.1 (OUT)
P1: IC2.15 (QA), JP3.6
P2: IC2.1 (QB), JP3.4
P3: IC2.2 (QC), JP3.2
P4: IC2.3 (QD), JP3.1
P5: IC2.4 (QE), JP3.3
P6: IC2.5 (QF), JP3.5
P7: IC2.6 (QG), JP3.11
P8: IC2.7 (QH), JP3.13
P9: IC3.15 (QA), JP3.15
REL_!OE: IC2.13 (G), IC3.13 (G), JP1.32
REL_DS: IC2.14 (SER), JP1.34
REL_SH_CP: IC2.11 (SCK), IC3.11 (SCK), JP1.36
REL_ST_CP: IC2.12 (RCK), IC3.12 (RCK), JP1.38
RTS: IC1.2 (RE/), IC1.3 (DE), JP1.21
RXD: IC1.1 (RO), JP1.12
TXD: IC1.4 (DI), JP1.14
VCC: C3.1, C6.1 (+), C7.1, C8.1, C9.1, C10.1, C11.1, IC1.8 (VCC), IC2.10 (SCL), IC2.16 (VCC), IC3.10 (SCL), IC3.16 (VCC), IC4.10 (SCL), IC4.16 (VCC), IC5.10 (SCL), IC5.16 (VCC), IC6.10 (SCL), IC6.16 (VCC), JP3.9, JP3.10, L1.2, U1.6 (FB), X2.L1.1 (P1.1), X2.L1.2 (P1.2)
VCC3.3V: JP1.2, JP1.16
VCC5V: JP1.1, JP1.3

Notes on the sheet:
Connector Relais/ BUS
Connector Banana Pro
RS-485
Termination
(optional)
Modbus Transceiver
Connector LED
Control LED
Control Relais
Connector 12VDC & ACCU
UPS Supply
Primary Supply
Logic Supply
Connector Banana Pro Power SATA
630mA
ACCU-
ACHTUNG!!! Connector erscheint gedreht im Vergleich zur PIN Belegung des Banana Pro!
Boden-
Boden+
Deckel-
Deckel+

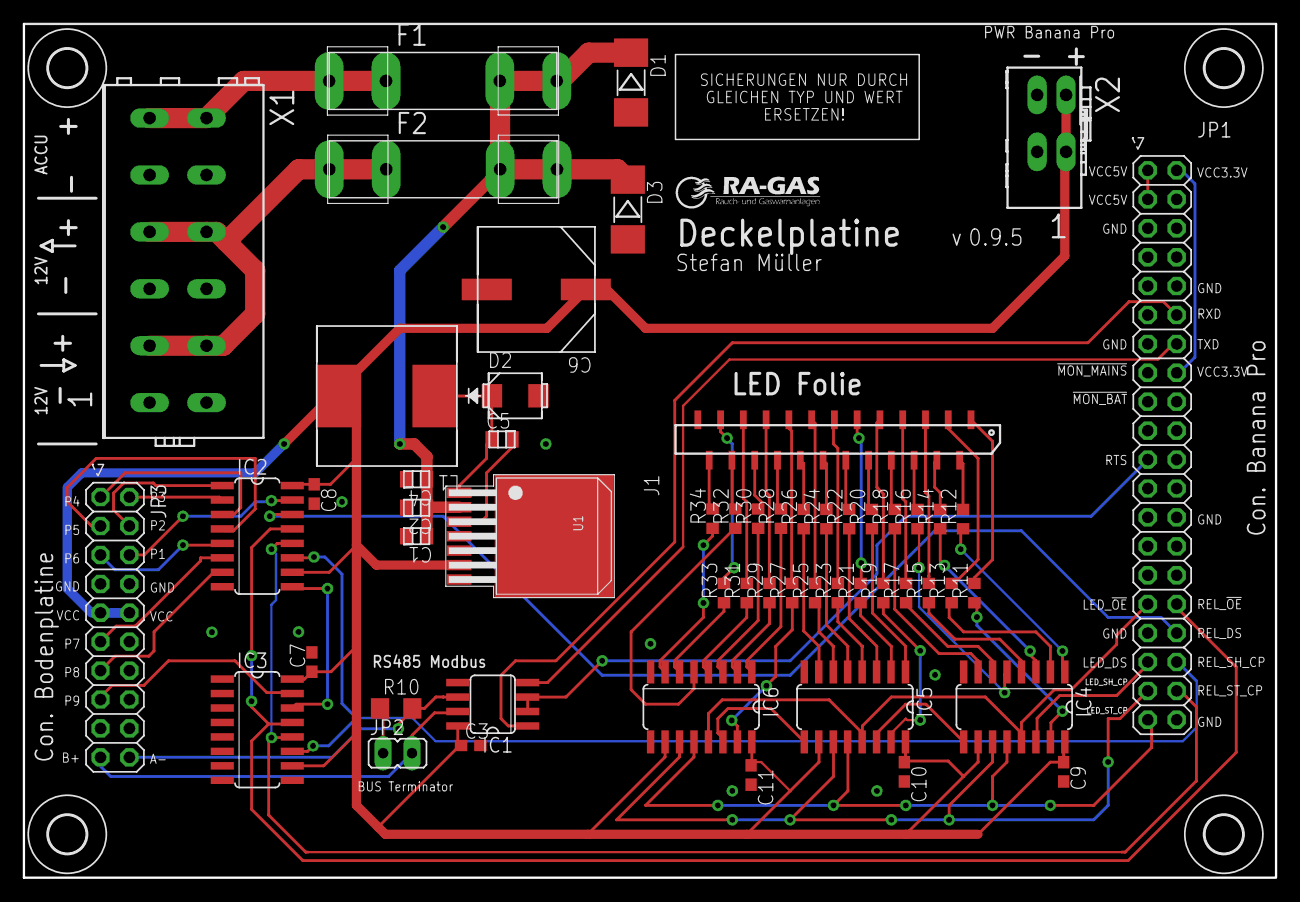
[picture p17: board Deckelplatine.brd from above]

Board: 2 copper layers, 110.0 x 75.0 mm, 62 parts (0 on the bottom side), 83 nets.

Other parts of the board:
U$2: LOGO_RA-GAS-SMALL
U$3: TEXT_NAME_VERSION_AUTHOR-SMALL
U$4: TEXT_FUSE-SMALL

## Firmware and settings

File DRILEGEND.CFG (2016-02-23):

InputUserCfg = 1
SymbolLayer = 144
SymbolSize = 40
SymbolWidth = 4
TextSize = 100.0000
TextRatio = 8
IdxFnt = 0
decMM = 2
decMIL = 0
SortHoles = 1
TolPlated = 0.02
TolNonPlated = 0.03
PlatedStatusNot = NOT
PlatedStatusBoth = BOTH
PlatedStatusYes = YES
VerticalChart = 1
HighCellFactor = 1.10
WideCellFactor = 1.10
CellOutline = 8
TitleOutline = 8
TableOutline = 16
SymbTitle = Symbol
ToolTitle = N°
MMTitle = mm
MilTitle = Mils
MicTitle = Mic
QtyTitle = Qty
TypeTitle = Plated
ToleTitle = Tol
SymbRank = 1
ToolRank = 2
MMRank = 3
MilRank = 4
MicRank = 0
QtyRank = 5
TypeRank = 6
ToleRank = 0
OutputDrillRack = 0
DrillRackFile = DRILLRACK.DRL
Unit = 0
OutputUserCfg = 1
UserCfgFile = DRILEGEND.CFG

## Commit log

2015-05-22 Erste Version der Eagle Projekt Dateien für xMZ_Mod
    Auf diesem Stand wurde heute, bei Farnell das Material für
    2 Bestückungen bestellt.
    Das PCB Board Design wird mit den Bauteilen zusammen durchgeführt.
    [Deckelplatine-order.xls, Deckelplatine.brd, Deckelplatine.sch]
2015-05-27 Begin mit dem Board Layout
    Erste Lieferung von Farnell angekommen.
    [Deckelplatine.brd, Deckelplatine.sch, OrderDetail-1.Lieferung.odf.ods]
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2015-06-01 Schema mit Verpolschutz an Vin und Accu.
    Schaltregler nach Application Note von Texas Instruments.
    Eingänge für den MON_MAINS und MON_BAT (GPIO Banana Pro Eingänge zur Überwachung Vin und Accu) sind durch NPN Transistoren gegen Überspannunge geschützt
    [Deckelplatine.brd, Deckelplatine.sch]
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2015-06-03 Erste ferige Version nach Tausch der Sicherung
    Board Layout, Schema, dicke Power Lines, neue Sicherung
    [Deckelplatine.brd, Deckelplatine.sch]
2015-06-05 Schaltregler überarbeitet, Teil 1
    CIN angepasst, Größe stimmte nicht (zu klein).
    Materialliste Farnell an Schaltplan "webench_design_4385517_7_60043841.pdf" angepasst.
    [Deckelplatine.brd, Deckelplatine.sch]
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2015-07-02 Erste Version in der PCB Produktion (Conrad)
    Dies ist die erste Produktion die über https://www.leiterplattenservice.com/
    abgewickelt wurde.
    https://www.leiterplattenservice.com/code/my_orderhistory_details.html?nr=CR558950f00063a
    Details:
    -------
    Nachfolgend sehen Sie die Details der gewählten Bestellung CR558950f00063a. Die Bestellung erfolgte am 23.06.2015, 14:28:32.
    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
    [Deckelplatine v090.brd, Deckelplatine v090.sch, Deckelplatine-order2.xls]
2015-07-07 Zwischen Commit Änderungen leider nicht mehr klar
    Leider habe ich vergessen welche Änderungen dieser Commit mit sich brachte.
    Desshalb sollte dieser komplett ignoriert werden.
    [Deckelplatine.brd, Deckelplatine.sch]
2015-07-07 Beta Version (v.0.9.1) begonnen
    Die Alpha Version (v.0.9.0) wurde produziert und bestückt.
    Erste Funktionstests waren alle erfolgreich.
    Somit beginnt mit diesem Commit nun die Beta Phase der
    Hardware Entwicklung.
    In diesem Commit sind viele (nicht alle) Datenblätter für die
    Komponenten der Hardware zu finden.
    [Deckelplatine v091 BOM.csv, Deckelplatine v091 BOM.ods, Deckelplatine v091.brd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]
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2016-01-20 Erste Version der Projekt eigenen Eagle Library
    Alle Parts sollen von nun an für jedes Projekt in eine seperate Eagle lbr Datei gepackt werden. Nur Teile aus dieser Library sollen verwendet werden.
    Das geschieht um einen besseren Überblick über die verwendeten Teile zu erhalten. Außerdem kann die Eagle Zeichnung incl. der Parts weiter gegeben werden.
    [Bodenplatine v001.brd]
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2016-01-25 Erste fast fertige Version des Schaltplans der Bodebplatine
    Es fehlt nur noch die Wago Klemme für L/N/PE Netzteil und 12V+/-
    [Bodenplatine v001.brd, Bodenplatine v001.sch]
2016-01-26 Begin mit dem Bord der Bodenplatine
    Schriften in den Schaltplänen einheitlich gemacht (Layer und Große)
    [Bodenplatine v001.brd, Bodenplatine v001.sch, Deckelplatine v091.sch]
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2016-01-26 Alle Bauteile auf dem Board, teilweise genau positioniert.
    GND ground plane auf beiden Seiten
    [Bodenplatine v001.brd, Bodenplatine v001.sch]
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2016-01-27 Relais Anschlüsse A1 und A2 im Schema gedreht
    [Bodenplatine v001.brd, Bodenplatine v001.sch]
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2016-01-27 Replace LL4148 Diode
    [Bodenplatine v001.brd, Bodenplatine v001.sch]
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2016-01-27 Dioden, Relais und mini Toggle Switch mit Daten von Farnell gefüttert
    [Bodenplatine v001.brd, Bodenplatine v001.sch]
2016-01-27 BOM und xlsx Datei für den Warenkorb import Farnell
    Die txt Datei wurde aus Eagle mit 'design link' exportiert
    Daraus dann mit LibreOffice eine xslx Datei generiert.
    [Bodenplatine v001-order.xlsx]
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2016-01-27 Prefix übernommen und GND plane im Board layout benannt
    [Bodenplatine v001.brd, Bodenplatine v001.sch]
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2016-01-28 Alle Datasheets der Bodenplatine vorhanden
    Auserdem noch einige Änderungen an den Footprints der Bodenplatine
    [Bodenplatine v001-order.xlsx, Bodenplatine v001.brd, Bodenplatine v001.sch]
2016-01-28 Logos auf dem Board und Außenmaße mit Kerben
    [Bodenplatine v001.brd, Bodenplatine v001.sch]
2016-01-28 Logos auch auf Schaltplan X und K Bezeichnungen auf Board verbessert
    [Bodenplatine v001.brd, Bodenplatine v001.sch]
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2016-02-08 Dateinamen umbenannt, die Versionsnummer wird in Git geführt
    [Deckelplatine.brd, Deckelplatine.sch]
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2016-02-09 Ein wenig Kosmetik auf der Deckelplatine
    Beschriftungen angepasst
    [Deckelplatine.brd, Deckelplatine.sch]
2016-02-17 Versionsnummer aus Dateinamen entfernt
    Git kann Versionsnummern viel besser verwalten.
    Ausserdem wurden ettliche 'alte' Dateien gelöscht. Sollten diese je wieder gebraucht werden dann kann der Git tag v0.9.0 ausgecheckt werden.
    Ä
    [Bodenplatine v001-order.xlsx, Bodenplatine.brd, Bodenplatine.sch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]
2016-02-17 Fix 12V Spannungsversorgung vergessen ><
    [Bodenplatine.brd, Bodenplatine.sch]
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2016-02-23 TOP und BOTTOM in Kupfer aufgebracht, so das keine Verwechslungen der Layer auftreten können
    [Bodenplatine.brd]
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

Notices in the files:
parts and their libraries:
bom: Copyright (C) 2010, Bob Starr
